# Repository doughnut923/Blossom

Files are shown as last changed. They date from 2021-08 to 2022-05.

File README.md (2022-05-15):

# Blossom

An open-sourced Alice/Arisu style keyboard case. Modified from [FateNozomi's Arisu](https://github.com/FateNozomi/arisu-case)

Hirakusu

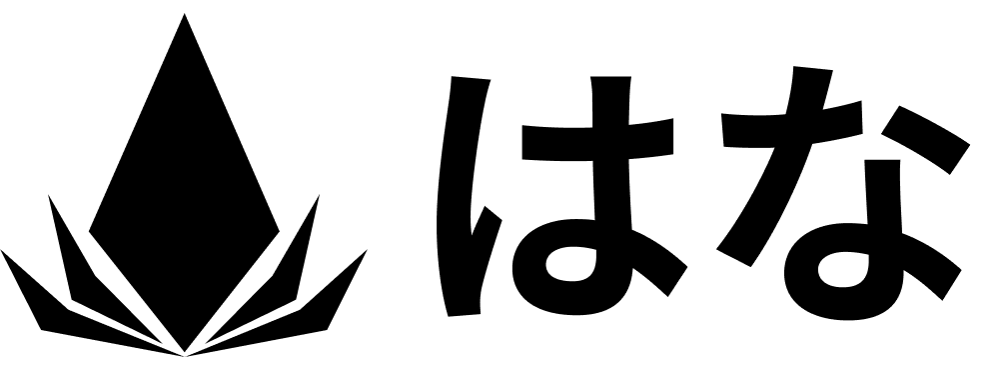
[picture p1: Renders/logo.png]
Hirakusu


## Features
- Designed for 3d printing
- Gasket Mounted Desgin using gasket strips on the side of the plate
   - Strip material: Poron Foam or Silicon Rubber
- Includes dxf files of sound dampening material between PCB and plate
- Compatible with [FateNozomi's PCB](https://github.com/FateNozomi/arisu-pcb)

## Layers

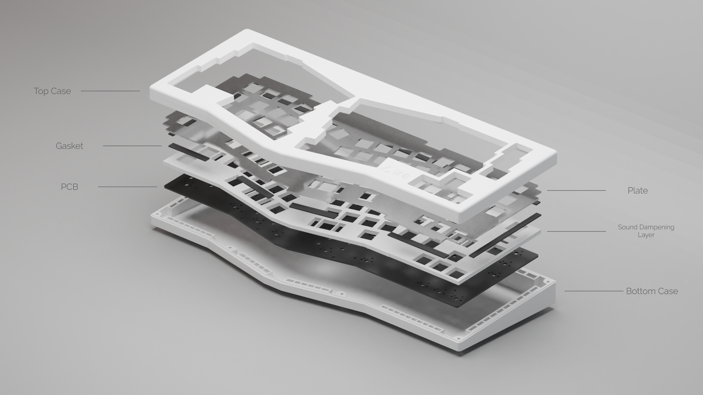
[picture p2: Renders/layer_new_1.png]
Layers


## Layout 

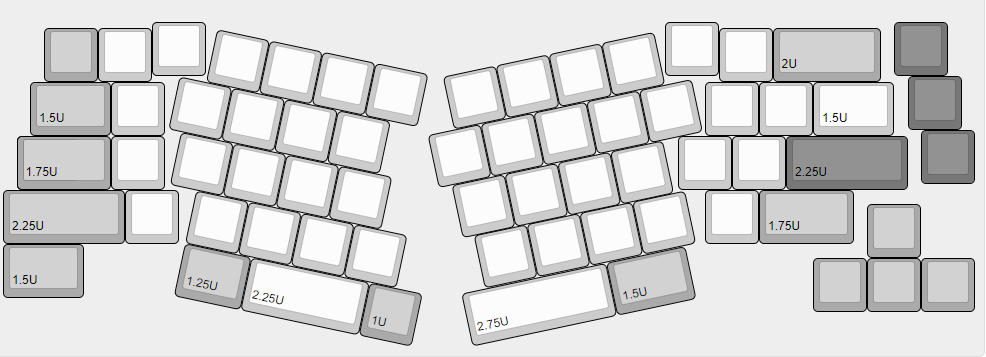
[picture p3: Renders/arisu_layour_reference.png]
layout ref


## Specifications 

- Dimensions: 30x142x375mm (DxHxW)
- Front Height: 16.5mm
- 5 degree typing angle

## About  the Repository
If you just want to build your own Blossom using the easiest steps just skip to [DIY Guide](#diy-guide)
Below is the contents of the respected folders in this GitHub Repo:
- `PCB files` - contains the Kicad project of the experimental version of the PCB(with underglow), modified from original FateNozomi's one.
- `Renders` - contains image assets.
- `blender` - contain Blender file of the case in case you need to do some edits to the model.
- ` case_stls` - stl files exported from Blender.
- `plate_dxfs` - contains dxf files for plate and gasket
- `production` - contains files necessary for DIY or production
- `qmk` - Modified keyboard firmware from arisu with added RGB underglow functionality.

# Notes
- **Use the files at your own risk**
- **PCB files are still under development,you can use it, but also at your own risk**

# DIY Guide
#### Things you need: 
| Item  | Image  | Description  | Related Files  | Place to Buy |
| --- | --- | --- | --- | --- |
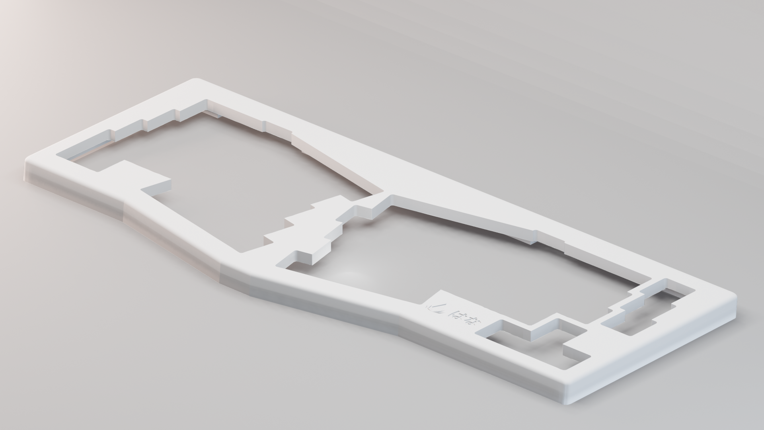
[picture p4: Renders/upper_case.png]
Upper Case
| Upper Case * 1  |   | Upper section of the case  | [U_Case.stl](https://github.com/DoughnutTheGuy/Blossom/blob/main/production/case/U_Case.stl)  |  [PCBWay](https://www.pcbway.com/rapid-prototyping/manufacture/?type=2&reffercode=TOP) |
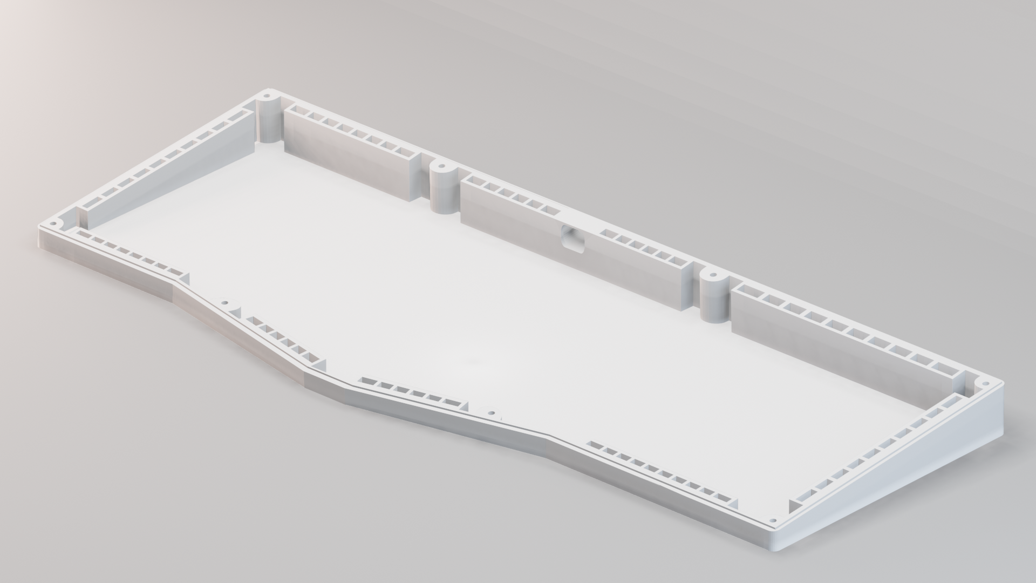
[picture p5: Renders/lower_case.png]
Lower Case
| Lower Case * 1  |   |  Lower Section of the case | [B_Case.stl](https://github.com/DoughnutTheGuy/Blossom/blob/main/production/case/B_Case.stl)  |  [PCBWay](https://www.pcbway.com/rapid-prototyping/manufacture/?type=2&reffercode=TOP) |
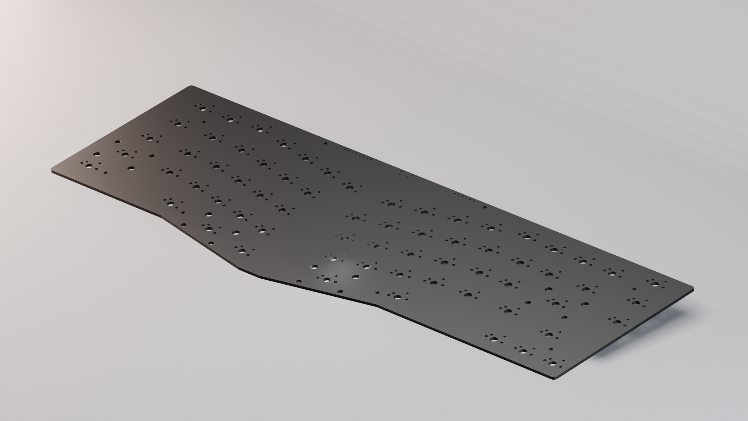
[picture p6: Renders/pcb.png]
PCB
|  PCB * 1  |   | Can be chosed from experimental version, which have backlight. Or original FateNozomi's version.  | Original: [gerber](https://github.com/DoughnutTheGuy/Blossom/blob/main/production/pcb/original/arisu-pcb-v1.1-gerber.zip) [bom](https://github.com/DoughnutTheGuy/Blossom/blob/main/production/pcb/original/arisu_bom.csv)  [CPL](https://github.com/DoughnutTheGuy/Blossom/blob/main/production/pcb/original/arisu-all-pos.csv)  Experimental: [gerber](https://github.com/DoughnutTheGuy/Blossom/blob/main/production/pcb/experimental/blossom-pcb.gerber.zip) [BOM](https://github.com/DoughnutTheGuy/Blossom/blob/main/production/pcb/experimental/arisu_bom.csv) [CPL](https://github.com/DoughnutTheGuy/Blossom/blob/main/production/pcb/experimental/arisu-all-pos.csv)| [JLPCB](https://jlcpcb.com) [PCBWay](https://www.pcbway.com) |
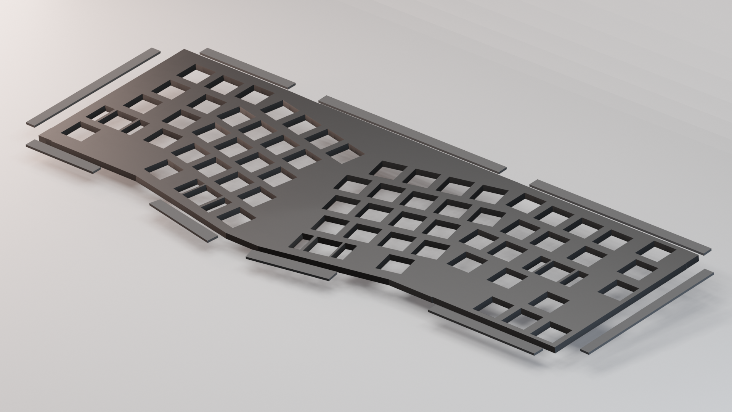
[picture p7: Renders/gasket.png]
Gasket
| Gasket & Sound Dampening Foam * 1  |   | Can be Poron or Silicon  | [gasket_n_sdl.dxf](https://github.com/DoughnutTheGuy/Blossom/blob/main/production/gasket/gasket_n_sdl.dxf)  | [TaoBao](https://item.taobao.com/item.htm?spm=a230r.1.14.38.46936e836dHYfA&id=637356500647&ns=1&abbucket=9#detail)  |
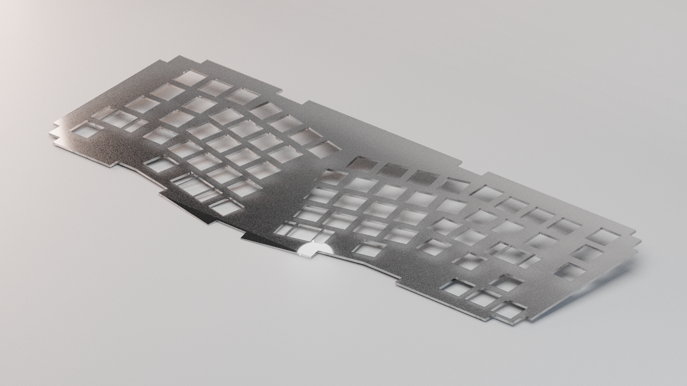
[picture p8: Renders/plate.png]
Plate
| Plate * 1 |   | /  |  [plate.dxf](https://github.com/DoughnutTheGuy/Blossom/blob/main/production/plate/plate.dxf) |  [Ponoko](https://www.ponoko.com/materials)  [TaoBao(PC)](https://item.taobao.com/item.htm?spm=a312a.7700824.w4004-18046735553.2.28ff1436zVjIGW&id=565729881968) [SendCutSend](https://sendcutsend.com/)|
| M2.5 Screws * 8 | /  | /  |  / | [Ebay](https://www.ebay.com/sch/i.html?_from=R40&_trksid=p2380057.m570.l1313&_nkw=m2.5+*+4+hex+screws&_sacat=0) [Taobao](https://detail.tmall.com/item.htm?id=18868040917&spm=a1z0k.7385993.0.0.58e537decwL3jP&skuId=4328080057495) |
| M2.5 Insert * 8 | /  | /  |  / |  [Amazon](https://www.amazon.com/Knurled-Threaded-Embedment-Assortment-M2-533-5%EF%BC%88100pcs%EF%BC%89/dp/B07SPWZT5G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) [Taobao](https://detail.tmall.com/item.htm?id=19528296472&spm=a1z0k.7385993.0.0.58e537decwL3jP) |

##### Other things you should probably have : Soldering Iron,  screw driver, switches, Hot Glue(Optional)

### Assembly
------------
**Step 1** - Install the switches into the plate

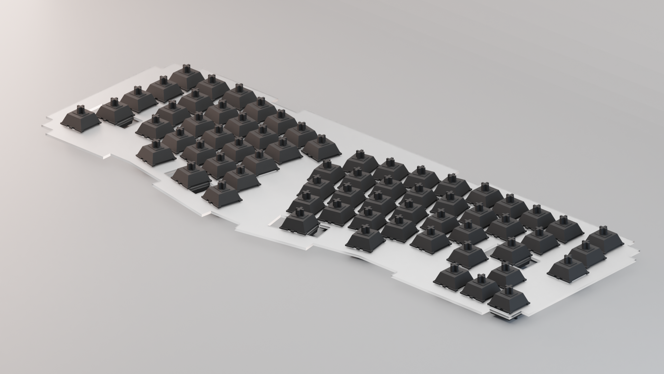
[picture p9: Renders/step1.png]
step 1


**Step 2** - place the sound dampening material between the plate and PCB

step 2

**Step 3** - Solder the switches

**Step 4** - Stick the gasket of the material of your choice to the extended positions on the plate

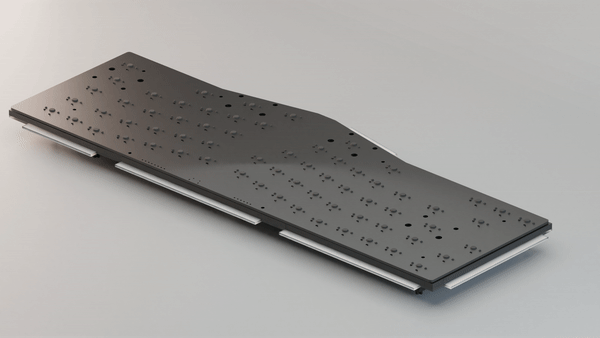
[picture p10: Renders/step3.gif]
step4


**Step 5**  - Install the M2.5 inserts in the 8 positions on the upper case shown below

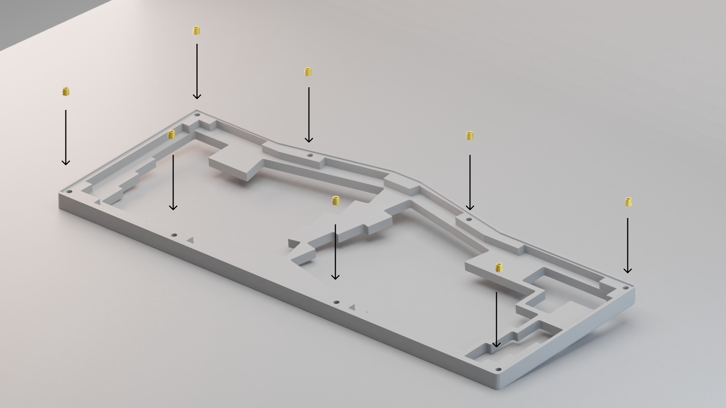
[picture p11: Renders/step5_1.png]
Step 5


**Step 6** - Place the plate with the pcb on top of the bottom case

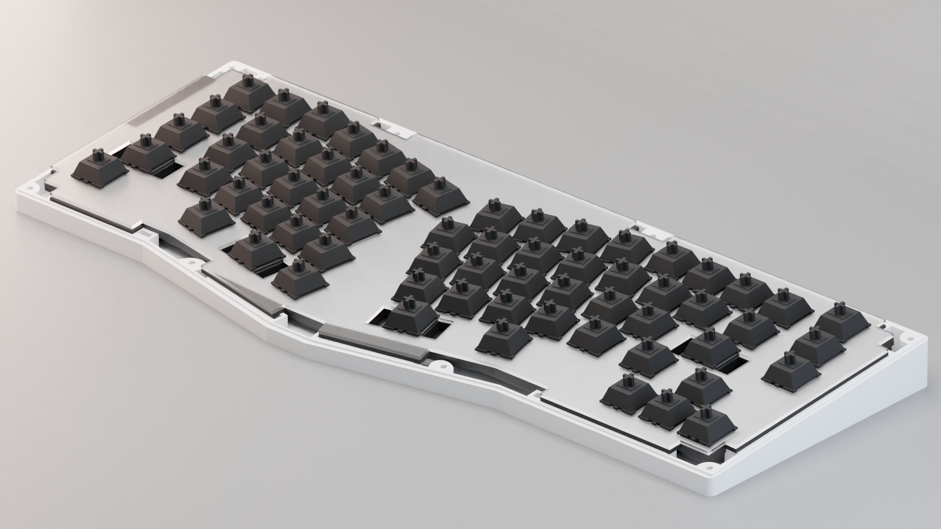
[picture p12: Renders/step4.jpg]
Step 6


**Step 7** - Cover it with the upper case

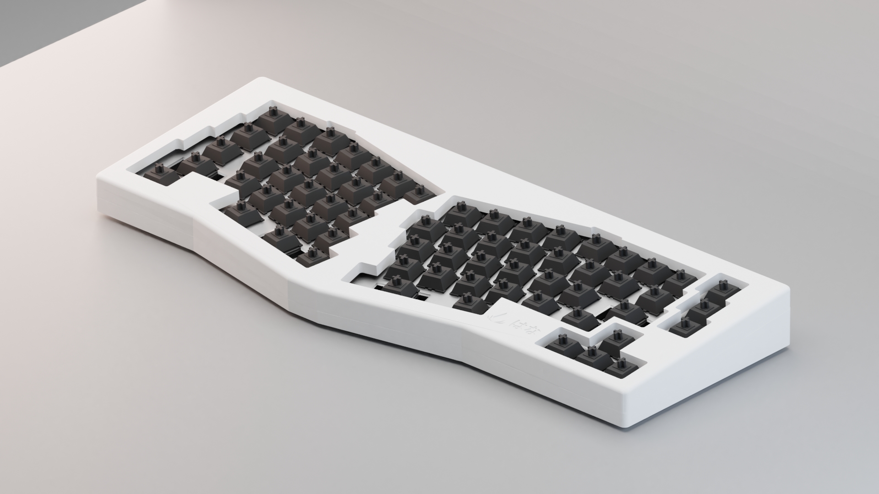
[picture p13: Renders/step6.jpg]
Step 7


**Step 8** - Install screw in the following positions to fix both upper and bottom case

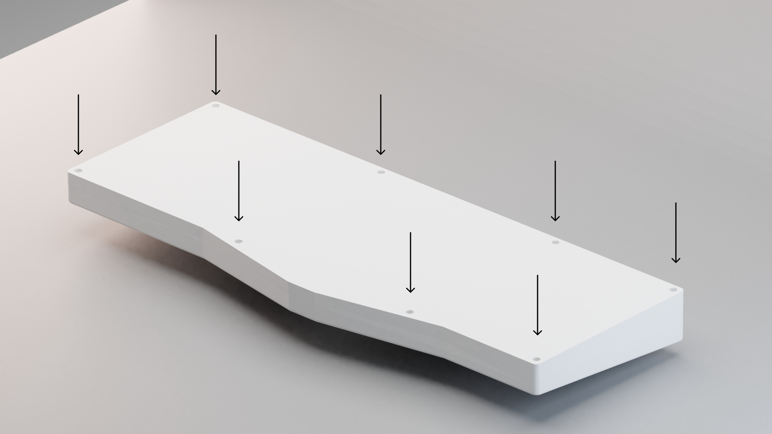
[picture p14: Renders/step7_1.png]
Final Step


**Final Step** - Connect your keyboard to a computer. Download the [Arisu Firmware from VIA](https://caniusevia.com/docs/download_firmware/#0) and fiash it to your keyboard. Tools such as [QMK Toolbox](https://github.com/qmk/qmk_toolbox) Is recommended. Here is a [quick guide](https://www.youtube.com/watch?v=fuBJbdCFF0Q&t=203s) on how to use QMK toolbox just for reference.

If you are using the experimental version. you need to change the `config.h` file's `RGB_DI_PIN`'s value to `F4`

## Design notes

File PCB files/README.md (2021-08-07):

This PCB is uder developnment

Only have support for underglow

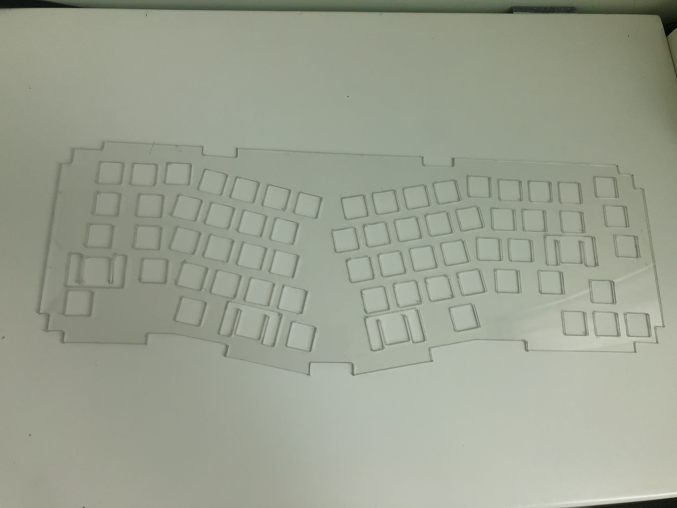
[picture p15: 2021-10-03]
Renders/proto_plate.jpg

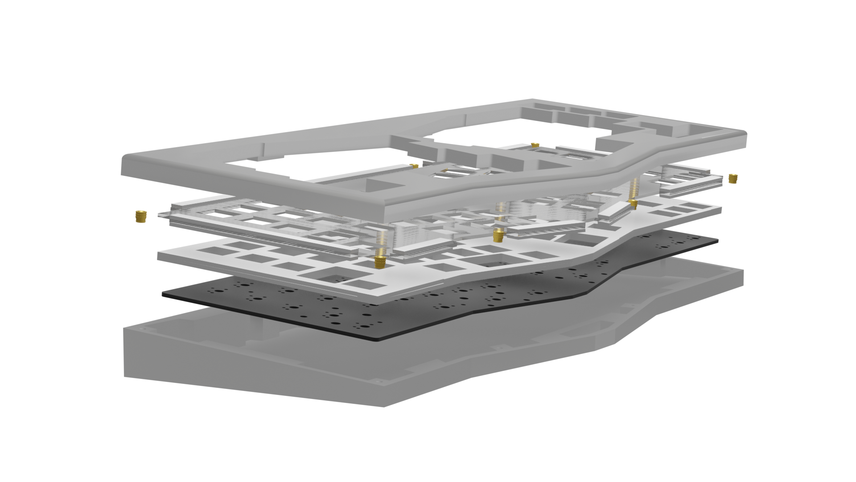
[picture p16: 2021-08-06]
Renders/layers.png

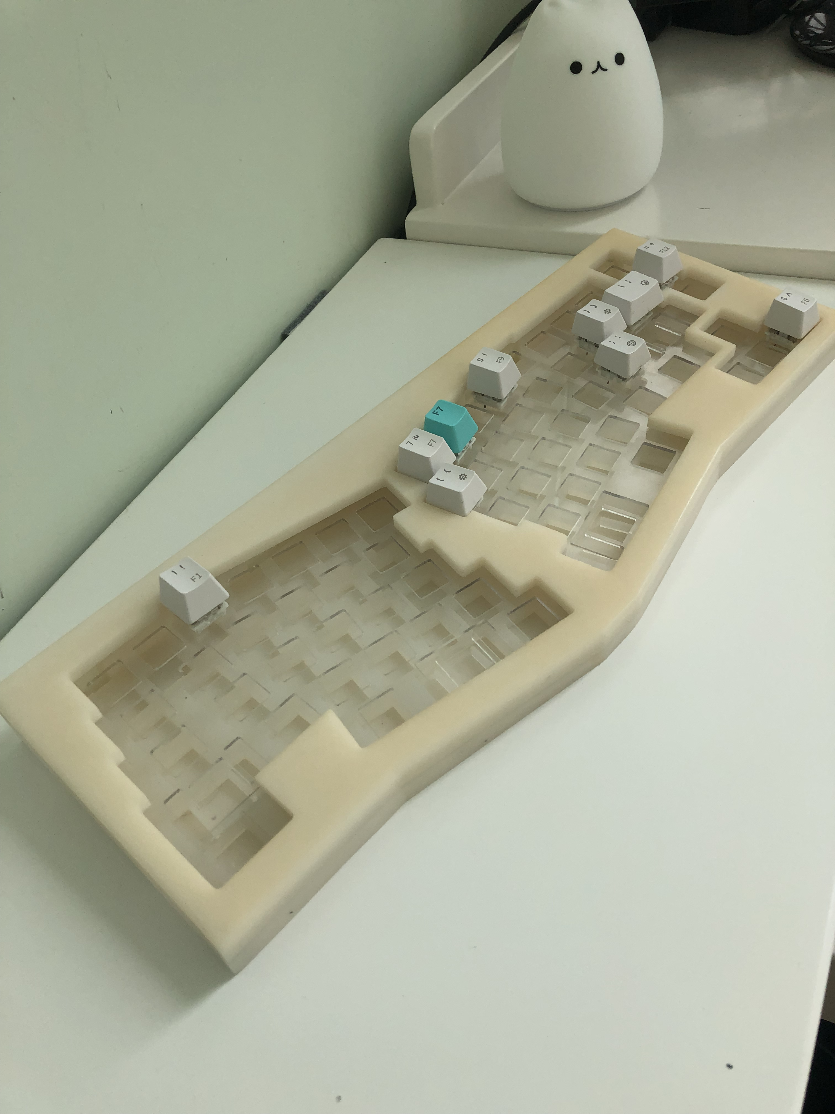
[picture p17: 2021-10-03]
Renders/proto_case.jpg

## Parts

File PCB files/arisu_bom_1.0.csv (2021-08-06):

Component | Description | Part | References | Value | Footprint | Quantity Per PCB | Datasheet
1 | Unpolarized capacitor | C | C6 C7 C8 C9 | 0.1uF | C_0805_HandSoldering | 4 | ~
2 | Unpolarized capacitor | C | C3 | 10uF | C_0805_HandSoldering | 1 | ~
3 | Unpolarized capacitor | C | C5 | 1uF | C_0805_HandSoldering | 1 | ~
4 | Unpolarized capacitor | C | C4 | 1uF (±10%) | C_0805_HandSoldering | 1 | ~
5 | Unpolarized capacitor | C | C1 C2 | 22pF | C_0805_HandSoldering | 2 | ~
6 | Diode | D | D1 D2 D3 D4 D5 D6 D7 D8 D9 D10 D11 D12 D13 D14 D15 D16 D17 D18 D19 D20 D21 D22 D23 D24 D25 D26 D27 D28 D29 D30 D31 D32 D33 D34 D35 D36 D37 D38 D39 D40 D41 D42 D43 D44 D45 D46 D47 D48 D49 D50 D51 D52 D53 D54 D55 D56 D57 D58 D59 D60 D61 D62 D63 D64 D65 D66 D67 | D | D_SOD-123 | 67 | ~
7 | Generic connector, single row, 01x01, script generated (kicad-library-utils/schlib/autogen/connector/) | Conn_01x01 | J13 | D+ | Pin_Header_Straight_1x01_Pitch2.54mm | 1 | ~
8 | Generic connector, single row, 01x01, script generated (kicad-library-utils/schlib/autogen/connector/) | Conn_01x01 | J14 | D- | Pin_Header_Straight_1x01_Pitch2.54mm | 1 | ~
9 | Generic connector, single row, 01x01, script generated (kicad-library-utils/schlib/autogen/connector/) | Conn_01x01 | J7 J15 | GND | Pin_Header_Straight_1x01_Pitch2.54mm | 2 | ~
10 | Generic connector, single row, 01x01, script generated (kicad-library-utils/schlib/autogen/connector/) | Conn_01x01 | J2 | MISO | Pin_Header_Straight_1x01_Pitch2.54mm | 1 | ~
11 | Generic connector, single row, 01x01, script generated (kicad-library-utils/schlib/autogen/connector/) | Conn_01x01 | J5 | MOSI | Pin_Header_Straight_1x01_Pitch2.54mm | 1 | ~
12 | Generic connector, single row, 01x01, script generated (kicad-library-utils/schlib/autogen/connector/) | Conn_01x01 | J8 | PF4 | Pin_Header_Straight_1x01_Pitch2.54mm | 1 | ~
13 | Generic connector, single row, 01x01, script generated (kicad-library-utils/schlib/autogen/connector/) | Conn_01x01 | J9 | PF5 | Pin_Header_Straight_1x01_Pitch2.54mm | 1 | ~
14 | Generic connector, single row, 01x01, script generated (kicad-library-utils/schlib/autogen/connector/) | Conn_01x01 | J10 | PF6 | Pin_Header_Straight_1x01_Pitch2.54mm | 1 | ~
15 | Generic connector, single row, 01x01, script generated (kicad-library-utils/schlib/autogen/connector/) | Conn_01x01 | J11 | PF7 | Pin_Header_Straight_1x01_Pitch2.54mm | 1 | ~
16 | Generic connector, single row, 01x01, script generated (kicad-library-utils/schlib/autogen/connector/) | Conn_01x01 | J6 | RES | Pin_Header_Straight_1x01_Pitch2.54mm | 1 | ~
17 | Generic connector, single row, 01x01, script generated (kicad-library-utils/schlib/autogen/connector/) | Conn_01x01 | J4 | SCK | Pin_Header_Straight_1x01_Pitch2.54mm | 1 | ~
18 | USB Micro Type B connector | USB_B_Micro | J1 | USB_B_Micro | USB_Micro-B_Molex-105017-0001 | 1 | ~
19 | Generic connector, single row, 01x01, script generated (kicad-library-utils/schlib/autogen/connector/) | Conn_01x01 | J3 J12 | VCC | Pin_Header_Straight_1x01_Pitch2.54mm | 2 | ~
20 | Resistor | R | R3 R4 | 10K | R_0805_HandSoldering | 2 | ~
21 | Resistor | R | R1 R2 | 22 | R_0805_HandSoldering | 2 | ~
22 | Push button switch, generic, two pins | SW_Push | SW1 SW6 SW7 SW8 SW9 SW10 SW11 SW12 SW13 SW15 SW16 SW17 SW18 SW19 SW20 SW21 SW22 SW24 SW25 SW26 SW27 SW28 SW29 SW30 SW31 SW32 SW33 SW34 SW35 SW36 SW38 SW39 SW40 SW41 SW42 SW43 SW44 SW45 SW47 SW48 SW49 SW50 SW51 SW52 SW53 SW55 SW56 SW58 SW59 SW61 SW62 SW63 SW64 SW65 SW66 SW67 | SW_Push | SW_Cherry_MX_1.00u_PCB | 56
23 | Push button switch, generic, two pins | SW_Push | SW2 SW5 SW14 SW46 SW60 | SW_Push | SW_Cherry_MX_1.50u_PCB | 5
24 | Push button switch, generic, two pins | SW_Push | SW23 | SW_Push | SW_Cherry_MX_2.00u_PCB_ReversedStabilizers | 1
25 | Push button switch, generic, two pins | SW_Push | SW3 SW54 | SW_Push | SW_Cherry_MX_1.75u_PCB | 2
26 | Push button switch, generic, two pins | SW_Push | SW37 | SW_Push | SW_Cherry_MX_2.75u_PCB_ReversedStabilizers | 1
27 | Push button switch, generic, two pins | SW_Push | SW4 | SW_Push | SW_Cherry_MX_2.25u_PCB | 1
28 | Push button switch, generic, two pins | SW_Push | SW57 | SW_Push | SW_Cherry_MX_2.25u_PCB_ReversedStabilizers | 1
29 | Push button switch, generic, two pins | SW_Push | SWR1 | SW_Push | SW_SPST_TL3342 | 1
30 | 16MHz, 32kB Flash, 2.5kB SRAM, 1kB EEPROM, USB 2.0, TQFP-44 | ATmega32U4-AU | U2 | ATmega32U4-AU | TQFP-44_10x10mm_Pitch0.8mm | 1 | http://ww1.microchip.com/downloads/en/DeviceDoc/Atmel-7766-8-bit-AVR-ATmega16U4-32U4_Datasheet.pdf
31 | Bidirectional ESD Protection Diode, SOT-23-6 | USBLC6-2SC6 | U1 | USBLC6-2SC6 | SOT-23-6_Handsoldering | 1 | http://www2.st.com/resource/en/datasheet/CD00050750.pdf
32 | Four pin crystal, GND on pins 2 and 4 | Crystal_GND24 | Y1 | Crystal_GND24 | Crystal_SMD_SeikoEpson_FA238-4pin_3.2x2.5mm_HandSoldering | 1 | ~
Component Groups: | 32
Component Count: | 166
Fitted Components: | 166
Number of PCBs: | 1
Total components: | 166
Schematic Version: | 1.0
Schematic Date:
BoM Date: | 2/10/2019 10:20:54 PM
Schematic Source: | D:\Users\Will\Documents\arisu-pcb\arisu.sch
KiCad Version: | Eeschema (5.0.2)-1

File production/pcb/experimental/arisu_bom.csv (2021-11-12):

Desginator | Comment | Footprint
C1, C2 | 22pF | Capacitor_SMD:C_0805_2012Metric
C3 | 10uF | Capacitor_SMD:C_0805_2012Metric
C4 | 1uF (+-10%) | Capacitor_SMD:C_0805_2012Metric
C5 | 1uF | Capacitor_SMD:C_0805_2012Metric
C6, C7, C8, C9 | 0.1uF | Capacitor_SMD:C_0805_2012Metric
D1, D2, D3, D4, D5, D6, D7, D8, D9, D10, D11, D12, D13, D14, D15, D16, D17, D18, D19, D20, D21, D22, D23, D24, D25, D26, D27, D28, D29, D30, D31, D32, D33, D34, D35, D36, D37, D38, D39, D40, D41, D42, D43, D44, D45, D46, D47, D48, D49, D50, D51, D52, D53, D54, D55, D56, D57, D58, D59, D60, D61, D62, D63, D64, D65, D66, D67 | D | Diodes_SMD:D_SOD-123
D68, D69, D70, D71, D72, D73, D74, D75, D76, D77, D78, D79, D80, D81, D82, D83 | WS2812B | LED_SMD:LED_WS2812B_PLCC4_5.0x5.0mm_P3.2mm
H1, H2, H3, H4, H5, H6, H7, H8 | MountingHole | Mounting_Holes:MountingHole_2.2mm_M2_Pad
J1 | USB_B_Micro | Connectors_USB:USB_Micro-B_Molex-105017-0001
R1, R2 | 22 | Resistor_SMD:R_0805_2012Metric
R3, R4 | 10K | Resistor_SMD:R_0805_2012Metric
R5 | 500 | Resistor_SMD:R_0805_2012Metric
SWR1 | SW_Push | Buttons_Switches_SMD:SW_SPST_TL3342
U1 | USBLC6-2SC6 | TO_SOT_Packages_SMD:SOT-23-6_Handsoldering
U2 | ATmega32U4-AU | Housings_QFP:TQFP-44_10x10mm_Pitch0.8mm
Y1 | Crystal_GND24 | Crystal:Crystal_SMD_3225-4Pin_3.2x2.5mm

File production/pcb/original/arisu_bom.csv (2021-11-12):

Designator | Comment | Footprint
C1, C2 | 22pF | Capacitors_SMD:C_0805_HandSoldering
C3 | 10uF | Capacitors_SMD:C_0805_HandSoldering
C4 | 1uF (±10%) | Capacitors_SMD:C_0805_HandSoldering
C5 | 1uF | Capacitors_SMD:C_0805_HandSoldering
C6, C7, C8, C9 | 0.1uF | Capacitors_SMD:C_0805_HandSoldering
D1, D2, D3, D4, D5, D6, D7, D8, D9, D10, D11, D12, D13, D14, D15, D16, D17, D18, D19, D20, D21, D22, D23, D24, D25, D26, D27, D28, D29, D30, D31, D32, D33, D34, D35, D36, D37, D38, D39, D40, D41, D42, D43, D44, D45, D46, D47, D48, D49, D50, D51, D52, D53, D54, D55, D56, D57, D58, D59, D60, D61, D62, D63, D64, D65, D66, D67 | D | Diodes_SMD:D_SOD-123
H1, H2, H3, H4, H5, H6, H7, H8 | MountingHole | Mounting_Holes:MountingHole_2.2mm_M2_Pad
J1 | USB_B_Micro | Connectors_USB:USB_Micro-B_Molex-105017-0001
J2 | MISO | Pin_Headers:Pin_Header_Straight_1x01_Pitch2.54mm
J3, J12 | VCC | Pin_Headers:Pin_Header_Straight_1x01_Pitch2.54mm
J4 | SCK | Pin_Headers:Pin_Header_Straight_1x01_Pitch2.54mm
J5 | MOSI | Pin_Headers:Pin_Header_Straight_1x01_Pitch2.54mm
J6 | RES | Pin_Headers:Pin_Header_Straight_1x01_Pitch2.54mm
J7, J15 | GND | Pin_Headers:Pin_Header_Straight_1x01_Pitch2.54mm
J8 | PF4 | Pin_Headers:Pin_Header_Straight_1x01_Pitch2.54mm
J9 | PF5 | Pin_Headers:Pin_Header_Straight_1x01_Pitch2.54mm
J10 | PF6 | Pin_Headers:Pin_Header_Straight_1x01_Pitch2.54mm
J11 | PF7 | Pin_Headers:Pin_Header_Straight_1x01_Pitch2.54mm
J13 | D+ | Pin_Headers:Pin_Header_Straight_1x01_Pitch2.54mm
J14 | D- | Pin_Headers:Pin_Header_Straight_1x01_Pitch2.54mm
R1, R2 | 22 | Resistors_SMD:R_0805_HandSoldering
R3, R4 | 10K | Resistors_SMD:R_0805_HandSoldering
SW1, SW6, SW7, SW8, SW9, SW10, SW11, SW12, SW13, SW15, SW16, SW17, SW18, SW19, SW20, SW21, SW22, SW24, SW25, SW26, SW27, SW28, SW29, SW30, SW31, SW32, SW33, SW34, SW35, SW36, SW38, SW39, SW40, SW41, SW42, SW43, SW44, SW45, SW47, SW48, SW49, SW50, SW51, SW52, SW53, SW55, SW56, SW58, SW59, SW61, SW62, SW63, SW64, SW65, SW66, SW67 | SW_Push | MX_Switch:SW_Cherry_MX_1.00u_PCB
SW2, SW5, SW14, SW46, SW60 | SW_Push | MX_Switch:SW_Cherry_MX_1.50u_PCB
SW3, SW54 | SW_Push | MX_Switch:SW_Cherry_MX_1.75u_PCB
SW4 | SW_Push | MX_Switch:SW_Cherry_MX_2.25u_PCB
SW23 | SW_Push | MX_Switch:SW_Cherry_MX_2.00u_PCB_ReversedStabilizers
SW37 | SW_Push | MX_Switch:SW_Cherry_MX_2.75u_PCB_ReversedStabilizers
SW57 | SW_Push | MX_Switch:SW_Cherry_MX_2.25u_PCB_ReversedStabilizers
SWR1 | SW_Push | Buttons_Switches_SMD:SW_SPST_TL3342
U1 | USBLC6-2SC6 | TO_SOT_Packages_SMD:SOT-23-6_Handsoldering
U2 | ATmega32U4-AU | Housings_QFP:TQFP-44_10x10mm_Pitch0.8mm
Y1 | Crystal_GND24 | Crystals:Crystal_SMD_SeikoEpson_FA238-4pin_3.2x2.5mm_HandSoldering

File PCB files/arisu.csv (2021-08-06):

Source: | C:\Users\asus\Desktop\Keybord Project\Final Folder\arisu-pcb-master\arisu.sch
Date: | 10/07/2021 18:01:36
Tool: | Eeschema (5.1.9)-1
Generator: | D:\Program Files\KiCad\bin\scripting\plugins/bom_csv_grouped_by_value.py
Component Count: | 191
Individual Components:
Item | Qty | Reference(s) | Value | LibPart | Footprint | Datasheet
 |  | C1 | 22pF | Device:C | Capacitor_SMD:C_0805_2012Metric | ~
 |  | C2 | 22pF | Device:C | Capacitor_SMD:C_0805_2012Metric | ~
 |  | C3 | 10uF | Device:C | Capacitor_SMD:C_0805_2012Metric | ~
 |  | C4 | 1uF (±10%) | Device:C | Capacitor_SMD:C_0805_2012Metric | ~
 |  | C5 | 1uF | Device:C | Capacitor_SMD:C_0805_2012Metric | ~
 |  | C6 | 0.1uF | Device:C | Capacitor_SMD:C_0805_2012Metric | ~
 |  | C7 | 0.1uF | Device:C | Capacitor_SMD:C_0805_2012Metric | ~
 |  | C8 | 0.1uF | Device:C | Capacitor_SMD:C_0805_2012Metric | ~
 |  | C9 | 0.1uF | Device:C | Capacitor_SMD:C_0805_2012Metric | ~
 |  | D1 | D | Device:D | Diodes_SMD:D_SOD-123 | ~
 |  | D2 | D | Device:D | Diodes_SMD:D_SOD-123 | ~
 |  | D3 | D | Device:D | Diodes_SMD:D_SOD-123 | ~
 |  | D4 | D | Device:D | Diodes_SMD:D_SOD-123 | ~
 |  | D5 | D | Device:D | Diodes_SMD:D_SOD-123 | ~
 |  | D6 | D | Device:D | Diodes_SMD:D_SOD-123 | ~
 |  | D7 | D | Device:D | Diodes_SMD:D_SOD-123 | ~
 |  | D8 | D | Device:D | Diodes_SMD:D_SOD-123 | ~
 |  | D9 | D | Device:D | Diodes_SMD:D_SOD-123 | ~
 |  | D10 | D | Device:D | Diodes_SMD:D_SOD-123 | ~
 |  | D11 | D | Device:D | Diodes_SMD:D_SOD-123 | ~
 |  | D12 | D | Device:D | Diodes_SMD:D_SOD-123 | ~
 |  | D13 | D | Device:D | Diodes_SMD:D_SOD-123 | ~
 |  | D14 | D | Device:D | Diodes_SMD:D_SOD-123 | ~
 |  | D15 | D | Device:D | Diodes_SMD:D_SOD-123 | ~
 |  | D16 | D | Device:D | Diodes_SMD:D_SOD-123 | ~
 |  | D17 | D | Device:D | Diodes_SMD:D_SOD-123 | ~
 |  | D18 | D | Device:D | Diodes_SMD:D_SOD-123 | ~
 |  | D19 | D | Device:D | Diodes_SMD:D_SOD-123 | ~
 |  | D20 | D | Device:D | Diodes_SMD:D_SOD-123 | ~
 |  | D21 | D | Device:D | Diodes_SMD:D_SOD-123 | ~
 |  | D22 | D | Device:D | Diodes_SMD:D_SOD-123 | ~
 |  | D23 | D | Device:D | Diodes_SMD:D_SOD-123 | ~
 |  | D24 | D | Device:D | Diodes_SMD:D_SOD-123 | ~
 |  | D25 | D | Device:D | Diodes_SMD:D_SOD-123 | ~
 |  | D26 | D | Device:D | Diodes_SMD:D_SOD-123 | ~
 |  | D27 | D | Device:D | Diodes_SMD:D_SOD-123 | ~
 |  | D28 | D | Device:D | Diodes_SMD:D_SOD-123 | ~
 |  | D29 | D | Device:D | Diodes_SMD:D_SOD-123 | ~
 |  | D30 | D | Device:D | Diodes_SMD:D_SOD-123 | ~
 |  | D31 | D | Device:D | Diodes_SMD:D_SOD-123 | ~
 |  | D32 | D | Device:D | Diodes_SMD:D_SOD-123 | ~
 |  | D33 | D | Device:D | Diodes_SMD:D_SOD-123 | ~
 |  | D34 | D | Device:D | Diodes_SMD:D_SOD-123 | ~
 |  | D35 | D | Device:D | Diodes_SMD:D_SOD-123 | ~
 |  | D36 | D | Device:D | Diodes_SMD:D_SOD-123 | ~
 |  | D37 | D | Device:D | Diodes_SMD:D_SOD-123 | ~
 |  | D38 | D | Device:D | Diodes_SMD:D_SOD-123 | ~
 |  | D39 | D | Device:D | Diodes_SMD:D_SOD-123 | ~
 |  | D40 | D | Device:D | Diodes_SMD:D_SOD-123 | ~
 |  | D41 | D | Device:D | Diodes_SMD:D_SOD-123 | ~
 |  | D42 | D | Device:D | Diodes_SMD:D_SOD-123 | ~
 |  | D43 | D | Device:D | Diodes_SMD:D_SOD-123 | ~
 |  | D44 | D | Device:D | Diodes_SMD:D_SOD-123 | ~
 |  | D45 | D | Device:D | Diodes_SMD:D_SOD-123 | ~
 |  | D46 | D | Device:D | Diodes_SMD:D_SOD-123 | ~
 |  | D47 | D | Device:D | Diodes_SMD:D_SOD-123 | ~
 |  | D48 | D | Device:D | Diodes_SMD:D_SOD-123 | ~
 |  | D49 | D | Device:D | Diodes_SMD:D_SOD-123 | ~
 |  | D50 | D | Device:D | Diodes_SMD:D_SOD-123 | ~
 |  | D51 | D | Device:D | Diodes_SMD:D_SOD-123 | ~
 |  | D52 | D | Device:D | Diodes_SMD:D_SOD-123 | ~
 |  | D53 | D | Device:D | Diodes_SMD:D_SOD-123 | ~
 |  | D54 | D | Device:D | Diodes_SMD:D_SOD-123 | ~
 |  | D55 | D | Device:D | Diodes_SMD:D_SOD-123 | ~
 |  | D56 | D | Device:D | Diodes_SMD:D_SOD-123 | ~
 |  | D57 | D | Device:D | Diodes_SMD:D_SOD-123 | ~
 |  | D58 | D | Device:D | Diodes_SMD:D_SOD-123 | ~
 |  | D59 | D | Device:D | Diodes_SMD:D_SOD-123 | ~
 |  | D60 | D | Device:D | Diodes_SMD:D_SOD-123 | ~
 |  | D61 | D | Device:D | Diodes_SMD:D_SOD-123 | ~
 |  | D62 | D | Device:D | Diodes_SMD:D_SOD-123 | ~
 |  | D63 | D | Device:D | Diodes_SMD:D_SOD-123 | ~
 |  | D64 | D | Device:D | Diodes_SMD:D_SOD-123 | ~
 |  | D65 | D | Device:D | Diodes_SMD:D_SOD-123 | ~
 |  | D66 | D | Device:D | Diodes_SMD:D_SOD-123 | ~
 |  | D67 | D | Device:D | Diodes_SMD:D_SOD-123 | ~
 |  | D68 | WS2812B | LED:WS2812B | LED_SMD:LED_WS2812B_PLCC4_5.0x5.0mm_P3.2mm | https://cdn-shop.adafruit.com/datasheets/WS2812B.pdf
 |  | D69 | WS2812B | LED:WS2812B | LED_SMD:LED_WS2812B_PLCC4_5.0x5.0mm_P3.2mm | https://cdn-shop.adafruit.com/datasheets/WS2812B.pdf
 |  | D70 | WS2812B | LED:WS2812B | LED_SMD:LED_WS2812B_PLCC4_5.0x5.0mm_P3.2mm | https://cdn-shop.adafruit.com/datasheets/WS2812B.pdf
 |  | D71 | WS2812B | LED:WS2812B | LED_SMD:LED_WS2812B_PLCC4_5.0x5.0mm_P3.2mm | https://cdn-shop.adafruit.com/datasheets/WS2812B.pdf
 |  | D72 | WS2812B | LED:WS2812B | LED_SMD:LED_WS2812B_PLCC4_5.0x5.0mm_P3.2mm | https://cdn-shop.adafruit.com/datasheets/WS2812B.pdf
 |  | D73 | WS2812B | LED:WS2812B | LED_SMD:LED_WS2812B_PLCC4_5.0x5.0mm_P3.2mm | https://cdn-shop.adafruit.com/datasheets/WS2812B.pdf
 |  | D74 | WS2812B | LED:WS2812B | LED_SMD:LED_WS2812B_PLCC4_5.0x5.0mm_P3.2mm | https://cdn-shop.adafruit.com/datasheets/WS2812B.pdf
 |  | D75 | WS2812B | LED:WS2812B | LED_SMD:LED_WS2812B_PLCC4_5.0x5.0mm_P3.2mm | https://cdn-shop.adafruit.com/datasheets/WS2812B.pdf
 |  | D76 | WS2812B | LED:WS2812B | LED_SMD:LED_WS2812B_PLCC4_5.0x5.0mm_P3.2mm | https://cdn-shop.adafruit.com/datasheets/WS2812B.pdf
 |  | D77 | WS2812B | LED:WS2812B | LED_SMD:LED_WS2812B_PLCC4_5.0x5.0mm_P3.2mm | https://cdn-shop.adafruit.com/datasheets/WS2812B.pdf
 |  | D78 | WS2812B | LED:WS2812B | LED_SMD:LED_WS2812B_PLCC4_5.0x5.0mm_P3.2mm | https://cdn-shop.adafruit.com/datasheets/WS2812B.pdf
 |  | D79 | WS2812B | LED:WS2812B | LED_SMD:LED_WS2812B_PLCC4_5.0x5.0mm_P3.2mm | https://cdn-shop.adafruit.com/datasheets/WS2812B.pdf
 |  | D80 | WS2812B | LED:WS2812B | LED_SMD:LED_WS2812B_PLCC4_5.0x5.0mm_P3.2mm | https://cdn-shop.adafruit.com/datasheets/WS2812B.pdf
 |  | D81 | WS2812B | LED:WS2812B | LED_SMD:LED_WS2812B_PLCC4_5.0x5.0mm_P3.2mm | https://cdn-shop.adafruit.com/datasheets/WS2812B.pdf
 |  | D82 | WS2812B | LED:WS2812B | LED_SMD:LED_WS2812B_PLCC4_5.0x5.0mm_P3.2mm | https://cdn-shop.adafruit.com/datasheets/WS2812B.pdf
 |  | D83 | WS2812B | LED:WS2812B | LED_SMD:LED_WS2812B_PLCC4_5.0x5.0mm_P3.2mm | https://cdn-shop.adafruit.com/datasheets/WS2812B.pdf
 |  | H1 | MountingHole | Mechanical:MountingHole | Mounting_Holes:MountingHole_2.2mm_M2_Pad | ~
 |  | H2 | MountingHole | Mechanical:MountingHole | Mounting_Holes:MountingHole_2.2mm_M2_Pad | ~
 |  | H3 | MountingHole | Mechanical:MountingHole | Mounting_Holes:MountingHole_2.2mm_M2_Pad | ~
 |  | H4 | MountingHole | Mechanical:MountingHole | Mounting_Holes:MountingHole_2.2mm_M2_Pad | ~
 |  | H5 | MountingHole | Mechanical:MountingHole | Mounting_Holes:MountingHole_2.2mm_M2_Pad | ~
 |  | H6 | MountingHole | Mechanical:MountingHole | Mounting_Holes:MountingHole_2.2mm_M2_Pad | ~
 |  | H7 | MountingHole | Mechanical:MountingHole | Mounting_Holes:MountingHole_2.2mm_M2_Pad | ~
 |  | H8 | MountingHole | Mechanical:MountingHole | Mounting_Holes:MountingHole_2.2mm_M2_Pad | ~
 |  | J1 | USB_B_Micro | Connector:USB_B_Micro | Connectors_USB:USB_Micro-B_Molex-105017-0001 | ~
 |  | J2 | MISO | Connector_Generic:Conn_01x01 | Pin_Headers:Pin_Header_Straight_1x01_Pitch2.54mm | ~
 |  | J3 | VCC | Connector_Generic:Conn_01x01 | Pin_Headers:Pin_Header_Straight_1x01_Pitch2.54mm | ~
 |  | J4 | SCK | Connector_Generic:Conn_01x01 | Pin_Headers:Pin_Header_Straight_1x01_Pitch2.54mm | ~
 |  | J5 | MOSI | Connector_Generic:Conn_01x01 | Pin_Headers:Pin_Header_Straight_1x01_Pitch2.54mm | ~
 |  | J6 | RES | Connector_Generic:Conn_01x01 | Pin_Headers:Pin_Header_Straight_1x01_Pitch2.54mm | ~
 |  | J7 | GND | Connector_Generic:Conn_01x01 | Pin_Headers:Pin_Header_Straight_1x01_Pitch2.54mm | ~
 |  | J8 | PF4 | Connector_Generic:Conn_01x01 | Pin_Headers:Pin_Header_Straight_1x01_Pitch2.54mm | ~
 |  | J9 | PF5 | Connector_Generic:Conn_01x01 | Pin_Headers:Pin_Header_Straight_1x01_Pitch2.54mm | ~
 |  | J10 | PF6 | Connector_Generic:Conn_01x01 | Pin_Headers:Pin_Header_Straight_1x01_Pitch2.54mm | ~
 |  | J11 | PF7 | Connector_Generic:Conn_01x01 | Pin_Headers:Pin_Header_Straight_1x01_Pitch2.54mm | ~
 |  | J12 | VCC | Connector_Generic:Conn_01x01 | Pin_Headers:Pin_Header_Straight_1x01_Pitch2.54mm | ~
 |  | J13 | D+ | Connector_Generic:Conn_01x01 | Pin_Headers:Pin_Header_Straight_1x01_Pitch2.54mm | ~
 |  | J14 | D- | Connector_Generic:Conn_01x01 | Pin_Headers:Pin_Header_Straight_1x01_Pitch2.54mm | ~
 |  | J15 | GND | Connector_Generic:Conn_01x01 | Pin_Headers:Pin_Header_Straight_1x01_Pitch2.54mm | ~
 |  | R1 | 22 | Device:R | Resistor_SMD:R_0805_2012Metric | ~
 |  | R2 | 22 | Device:R | Resistor_SMD:R_0805_2012Metric | ~
 |  | R3 | 10K | Device:R | Resistor_SMD:R_0805_2012Metric | ~
 |  | R4 | 10K | Device:R | Resistor_SMD:R_0805_2012Metric | ~
 |  | R5 | 500 | Device:R | Resistor_SMD:R_0805_2012Metric | ~
 |  | SW1 | SW_Push | Switch:SW_Push | MX_Switch:SW_Cherry_MX_1.00u_PCB
 |  | SW2 | SW_Push | Switch:SW_Push | MX_Switch:SW_Cherry_MX_1.50u_PCB
 |  | SW3 | SW_Push | Switch:SW_Push | MX_Switch:SW_Cherry_MX_1.75u_PCB
 |  | SW4 | SW_Push | Switch:SW_Push | MX_Switch:SW_Cherry_MX_2.25u_PCB
 |  | SW5 | SW_Push | Switch:SW_Push | MX_Switch:SW_Cherry_MX_1.50u_PCB
 |  | SW6 | SW_Push | Switch:SW_Push | MX_Switch:SW_Cherry_MX_1.00u_PCB
 |  | SW7 | SW_Push | Switch:SW_Push | MX_Switch:SW_Cherry_MX_1.00u_PCB
 |  | SW8 | SW_Push | Switch:SW_Push | MX_Switch:SW_Cherry_MX_1.00u_PCB
 |  | SW9 | SW_Push | Switch:SW_Push | MX_Switch:SW_Cherry_MX_1.00u_PCB
 |  | SW10 | SW_Push | Switch:SW_Push | MX_Switch:SW_Cherry_MX_1.00u_PCB
 |  | SW11 | SW_Push | Switch:SW_Push | MX_Switch:SW_Cherry_MX_1.00u_PCB
 |  | SW12 | SW_Push | Switch:SW_Push | MX_Switch:SW_Cherry_MX_1.00u_PCB
 |  | SW13 | SW_Push | Switch:SW_Push | MX_Switch:SW_Cherry_MX_1.00u_PCB
 |  | SW14 | SW_Push | Switch:SW_Push | MX_Switch:SW_Cherry_MX_1.50u_PCB
 |  | SW15 | SW_Push | Switch:SW_Push | MX_Switch:SW_Cherry_MX_1.00u_PCB
 |  | SW16 | SW_Push | Switch:SW_Push | MX_Switch:SW_Cherry_MX_1.00u_PCB
 |  | SW17 | SW_Push | Switch:SW_Push | MX_Switch:SW_Cherry_MX_1.00u_PCB
 |  | SW18 | SW_Push | Switch:SW_Push | MX_Switch:SW_Cherry_MX_1.00u_PCB
 |  | SW19 | SW_Push | Switch:SW_Push | MX_Switch:SW_Cherry_MX_1.00u_PCB
 |  | SW20 | SW_Push | Switch:SW_Push | MX_Switch:SW_Cherry_MX_1.00u_PCB
 |  | SW21 | SW_Push | Switch:SW_Push | MX_Switch:SW_Cherry_MX_1.00u_PCB
 |  | SW22 | SW_Push | Switch:SW_Push | MX_Switch:SW_Cherry_MX_1.00u_PCB
 |  | SW23 | SW_Push | Switch:SW_Push | MX_Switch:SW_Cherry_MX_2.00u_PCB_ReversedStabilizers
 |  | SW24 | SW_Push | Switch:SW_Push | MX_Switch:SW_Cherry_MX_1.00u_PCB
 |  | SW25 | SW_Push | Switch:SW_Push | MX_Switch:SW_Cherry_MX_1.00u_PCB
 |  | SW26 | SW_Push | Switch:SW_Push | MX_Switch:SW_Cherry_MX_1.00u_PCB
 |  | SW27 | SW_Push | Switch:SW_Push | MX_Switch:SW_Cherry_MX_1.00u_PCB
 |  | SW28 | SW_Push | Switch:SW_Push | MX_Switch:SW_Cherry_MX_1.00u_PCB
 |  | SW29 | SW_Push | Switch:SW_Push | MX_Switch:SW_Cherry_MX_1.00u_PCB
 |  | SW30 | SW_Push | Switch:SW_Push | MX_Switch:SW_Cherry_MX_1.00u_PCB
 |  | SW31 | SW_Push | Switch:SW_Push | MX_Switch:SW_Cherry_MX_1.00u_PCB
 |  | SW32 | SW_Push | Switch:SW_Push | MX_Switch:SW_Cherry_MX_1.00u_PCB
 |  | SW33 | SW_Push | Switch:SW_Push | MX_Switch:SW_Cherry_MX_1.00u_PCB
 |  | SW34 | SW_Push | Switch:SW_Push | MX_Switch:SW_Cherry_MX_1.00u_PCB
 |  | SW35 | SW_Push | Switch:SW_Push | MX_Switch:SW_Cherry_MX_1.00u_PCB
 |  | SW36 | SW_Push | Switch:SW_Push | MX_Switch:SW_Cherry_MX_1.00u_PCB
 |  | SW37 | SW_Push | Switch:SW_Push | MX_Switch:SW_Cherry_MX_2.75u_PCB_ReversedStabilizers
 |  | SW38 | SW_Push | Switch:SW_Push | MX_Switch:SW_Cherry_MX_1.00u_PCB
 |  | SW39 | SW_Push | Switch:SW_Push | MX_Switch:SW_Cherry_MX_1.00u_PCB
 |  | SW40 | SW_Push | Switch:SW_Push | MX_Switch:SW_Cherry_MX_1.00u_PCB
 |  | SW41 | SW_Push | Switch:SW_Push | MX_Switch:SW_Cherry_MX_1.00u_PCB
 |  | SW42 | SW_Push | Switch:SW_Push | MX_Switch:SW_Cherry_MX_1.00u_PCB
 |  | SW43 | SW_Push | Switch:SW_Push | MX_Switch:SW_Cherry_MX_1.00u_PCB
 |  | SW44 | SW_Push | Switch:SW_Push | MX_Switch:SW_Cherry_MX_1.00u_PCB
 |  | SW45 | SW_Push | Switch:SW_Push | MX_Switch:SW_Cherry_MX_1.00u_PCB
 |  | SW46 | SW_Push | Switch:SW_Push | MX_Switch:SW_Cherry_MX_1.50u_PCB
 |  | SW47 | SW_Push | Switch:SW_Push | MX_Switch:SW_Cherry_MX_1.00u_PCB
 |  | SW48 | SW_Push | Switch:SW_Push | MX_Switch:SW_Cherry_MX_1.00u_PCB
 |  | SW49 | SW_Push | Switch:SW_Push | MX_Switch:SW_Cherry_MX_1.00u_PCB
 |  | SW50 | SW_Push | Switch:SW_Push | MX_Switch:SW_Cherry_MX_1.00u_PCB
 |  | SW51 | SW_Push | Switch:SW_Push | MX_Switch:SW_Cherry_MX_1.00u_PCB
 |  | SW52 | SW_Push | Switch:SW_Push | MX_Switch:SW_Cherry_MX_1.00u_PCB
 |  | SW53 | SW_Push | Switch:SW_Push | MX_Switch:SW_Cherry_MX_1.00u_PCB
 |  | SW54 | SW_Push | Switch:SW_Push | MX_Switch:SW_Cherry_MX_1.75u_PCB
 |  | SW55 | SW_Push | Switch:SW_Push | MX_Switch:SW_Cherry_MX_1.00u_PCB
 |  | SW56 | SW_Push | Switch:SW_Push | MX_Switch:SW_Cherry_MX_1.00u_PCB
 |  | SW57 | SW_Push | Switch:SW_Push | MX_Switch:SW_Cherry_MX_2.25u_PCB_ReversedStabilizers
 |  | SW58 | SW_Push | Switch:SW_Push | MX_Switch:SW_Cherry_MX_1.00u_PCB
 |  | SW59 | SW_Push | Switch:SW_Push | MX_Switch:SW_Cherry_MX_1.00u_PCB
 |  | SW60 | SW_Push | Switch:SW_Push | MX_Switch:SW_Cherry_MX_1.50u_PCB
 |  | SW61 | SW_Push | Switch:SW_Push | MX_Switch:SW_Cherry_MX_1.00u_PCB
 |  | SW62 | SW_Push | Switch:SW_Push | MX_Switch:SW_Cherry_MX_1.00u_PCB
 |  | SW63 | SW_Push | Switch:SW_Push | MX_Switch:SW_Cherry_MX_1.00u_PCB
 |  | SW64 | SW_Push | Switch:SW_Push | MX_Switch:SW_Cherry_MX_1.00u_PCB
 |  | SW65 | SW_Push | Switch:SW_Push | MX_Switch:SW_Cherry_MX_1.00u_PCB
 |  | SW66 | SW_Push | Switch:SW_Push | MX_Switch:SW_Cherry_MX_1.00u_PCB
 |  | SW67 | SW_Push | Switch:SW_Push | MX_Switch:SW_Cherry_MX_1.00u_PCB
 |  | SWR1 | SW_Push | Switch:SW_Push | Buttons_Switches_SMD:SW_SPST_TL3342
 |  | U1 | USBLC6-2SC6 | Power_Protection:USBLC6-2SC6 | TO_SOT_Packages_SMD:SOT-23-6_Handsoldering | http://www2.st.com/resource/en/datasheet/CD00050750.pdf
 |  | U2 | ATmega32U4-AU | MCU_Microchip_ATmega:ATmega32U4-AU | Housings_QFP:TQFP-44_10x10mm_Pitch0.8mm | http://ww1.microchip.com/downloads/en/DeviceDoc/Atmel-7766-8-bit-AVR-ATmega16U4-32U4_Datasheet.pdf
 |  | Y1 | Crystal_GND24 | Device:Crystal_GND24 | Crystal:Crystal_SMD_3225-4Pin_3.2x2.5mm | ~
Collated Components:
Item | Qty | Reference(s) | Value | LibPart | Footprint | Datasheet
1 | 2 | C1, C2 | 22pF | Device:C | Capacitor_SMD:C_0805_2012Metric | ~
2 | 1 | C3 | 10uF | Device:C | Capacitor_SMD:C_0805_2012Metric | ~
3 | 1 | C4 | 1uF (±10%) | Device:C | Capacitor_SMD:C_0805_2012Metric | ~
4 | 1 | C5 | 1uF | Device:C | Capacitor_SMD:C_0805_2012Metric | ~
5 | 4 | C6, C7, C8, C9 | 0.1uF | Device:C | Capacitor_SMD:C_0805_2012Metric | ~
6 | 67 | D1, D2, D3, D4, D5, D6, D7, D8, D9, D10, D11, D12, D13, D14, D15, D16, D17, D18, D19, D20, D21, D22, D23, D24, D25, D26, D27, D28, D29, D30, D31, D32, D33, D34, D35, D36, D37, D38, D39, D40, D41, D42, D43, D44, D45, D46, D47, D48, D49, D50, D51, D52, D53, D54, D55, D56, D57, D58, D59, D60, D61, D62, D63, D64, D65, D66, D67 | D | Device:D | Diodes_SMD:D_SOD-123 | ~
7 | 16 | D68, D69, D70, D71, D72, D73, D74, D75, D76, D77, D78, D79, D80, D81, D82, D83 | WS2812B | LED:WS2812B | LED_SMD:LED_WS2812B_PLCC4_5.0x5.0mm_P3.2mm | https://cdn-shop.adafruit.com/datasheets/WS2812B.pdf
8 | 8 | H1, H2, H3, H4, H5, H6, H7, H8 | MountingHole | Mechanical:MountingHole | Mounting_Holes:MountingHole_2.2mm_M2_Pad | ~
9 | 1 | J1 | USB_B_Micro | Connector:USB_B_Micro | Connectors_USB:USB_Micro-B_Molex-105017-0001 | ~
10 | 1 | J2 | MISO | Connector_Generic:Conn_01x01 | Pin_Headers:Pin_Header_Straight_1x01_Pitch2.54mm | ~
11 | 2 | J3, J12 | VCC | Connector_Generic:Conn_01x01 | Pin_Headers:Pin_Header_Straight_1x01_Pitch2.54mm | ~
12 | 1 | J4 | SCK | Connector_Generic:Conn_01x01 | Pin_Headers:Pin_Header_Straight_1x01_Pitch2.54mm | ~
13 | 1 | J5 | MOSI | Connector_Generic:Conn_01x01 | Pin_Headers:Pin_Header_Straight_1x01_Pitch2.54mm | ~
14 | 1 | J6 | RES | Connector_Generic:Conn_01x01 | Pin_Headers:Pin_Header_Straight_1x01_Pitch2.54mm | ~
15 | 2 | J7, J15 | GND | Connector_Generic:Conn_01x01 | Pin_Headers:Pin_Header_Straight_1x01_Pitch2.54mm | ~
16 | 1 | J8 | PF4 | Connector_Generic:Conn_01x01 | Pin_Headers:Pin_Header_Straight_1x01_Pitch2.54mm | ~
17 | 1 | J9 | PF5 | Connector_Generic:Conn_01x01 | Pin_Headers:Pin_Header_Straight_1x01_Pitch2.54mm | ~
18 | 1 | J10 | PF6 | Connector_Generic:Conn_01x01 | Pin_Headers:Pin_Header_Straight_1x01_Pitch2.54mm | ~
19 | 1 | J11 | PF7 | Connector_Generic:Conn_01x01 | Pin_Headers:Pin_Header_Straight_1x01_Pitch2.54mm | ~
20 | 1 | J13 | D+ | Connector_Generic:Conn_01x01 | Pin_Headers:Pin_Header_Straight_1x01_Pitch2.54mm | ~
21 | 1 | J14 | D- | Connector_Generic:Conn_01x01 | Pin_Headers:Pin_Header_Straight_1x01_Pitch2.54mm | ~
22 | 2 | R1, R2 | 22 | Device:R | Resistor_SMD:R_0805_2012Metric | ~
23 | 2 | R3, R4 | 10K | Device:R | Resistor_SMD:R_0805_2012Metric | ~
24 | 1 | R5 | 500 | Device:R | Resistor_SMD:R_0805_2012Metric | ~
25 | 56 | SW1, SW6, SW7, SW8, SW9, SW10, SW11, SW12, SW13, SW15, SW16, SW17, SW18, SW19, SW20, SW21, SW22, SW24, SW25, SW26, SW27, SW28, SW29, SW30, SW31, SW32, SW33, SW34, SW35, SW36, SW38, SW39, SW40, SW41, SW42, SW43, SW44, SW45, SW47, SW48, SW49, SW50, SW51, SW52, SW53, SW55, SW56, SW58, SW59, SW61, SW62, SW63, SW64, SW65, SW66, SW67 | SW_Push | Switch:SW_Push | MX_Switch:SW_Cherry_MX_1.00u_PCB
26 | 5 | SW2, SW5, SW14, SW46, SW60 | SW_Push | Switch:SW_Push | MX_Switch:SW_Cherry_MX_1.50u_PCB
27 | 2 | SW3, SW54 | SW_Push | Switch:SW_Push | MX_Switch:SW_Cherry_MX_1.75u_PCB
28 | 1 | SW4 | SW_Push | Switch:SW_Push | MX_Switch:SW_Cherry_MX_2.25u_PCB
29 | 1 | SW23 | SW_Push | Switch:SW_Push | MX_Switch:SW_Cherry_MX_2.00u_PCB_ReversedStabilizers
30 | 1 | SW37 | SW_Push | Switch:SW_Push | MX_Switch:SW_Cherry_MX_2.75u_PCB_ReversedStabilizers
31 | 1 | SW57 | SW_Push | Switch:SW_Push | MX_Switch:SW_Cherry_MX_2.25u_PCB_ReversedStabilizers
32 | 1 | SWR1 | SW_Push | Switch:SW_Push | Buttons_Switches_SMD:SW_SPST_TL3342
33 | 1 | U1 | USBLC6-2SC6 | Power_Protection:USBLC6-2SC6 | TO_SOT_Packages_SMD:SOT-23-6_Handsoldering | http://www2.st.com/resource/en/datasheet/CD00050750.pdf
34 | 1 | U2 | ATmega32U4-AU | MCU_Microchip_ATmega:ATmega32U4-AU | Housings_QFP:TQFP-44_10x10mm_Pitch0.8mm | http://ww1.microchip.com/downloads/en/DeviceDoc/Atmel-7766-8-bit-AVR-ATmega16U4-32U4_Datasheet.pdf
35 | 1 | Y1 | Crystal_GND24 | Device:Crystal_GND24 | Crystal:Crystal_SMD_3225-4Pin_3.2x2.5mm | ~

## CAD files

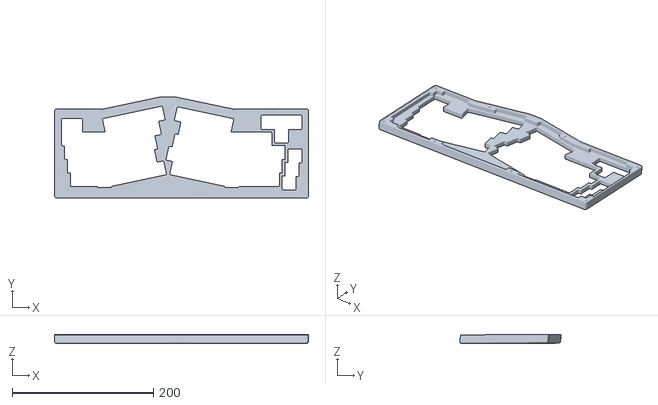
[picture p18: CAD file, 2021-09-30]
case_stls/new_top-Top_Case_without_logo.stl
359.3 x 143.4 x 12.9

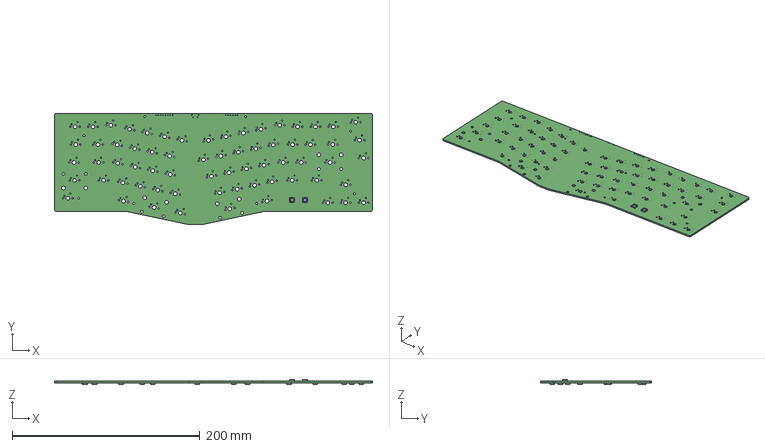
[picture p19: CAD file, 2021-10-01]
PCB files/blossom_pcb/arisu.step
339.1 x 118.7 x 4.90 mm

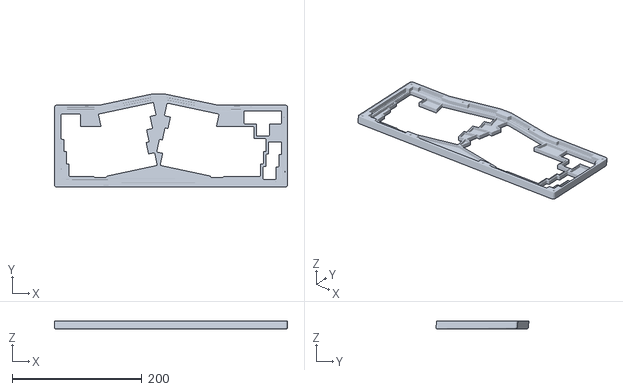
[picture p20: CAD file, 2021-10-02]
production/case/U_Case.stl
359.3 x 143.4 x 12.9

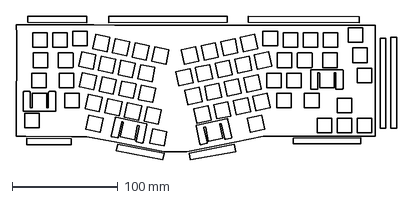
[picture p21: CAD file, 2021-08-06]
production/gasket/gasket_n_sdl.dxf
360.5 x 136.1 mm

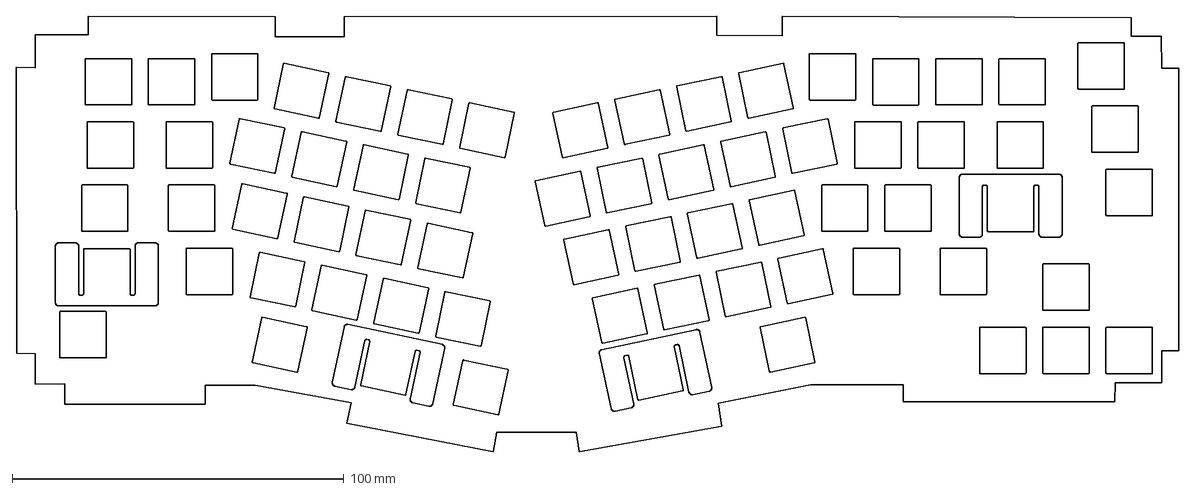
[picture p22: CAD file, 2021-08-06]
production/plate/plate.dxf
350.4 x 131.4 mm

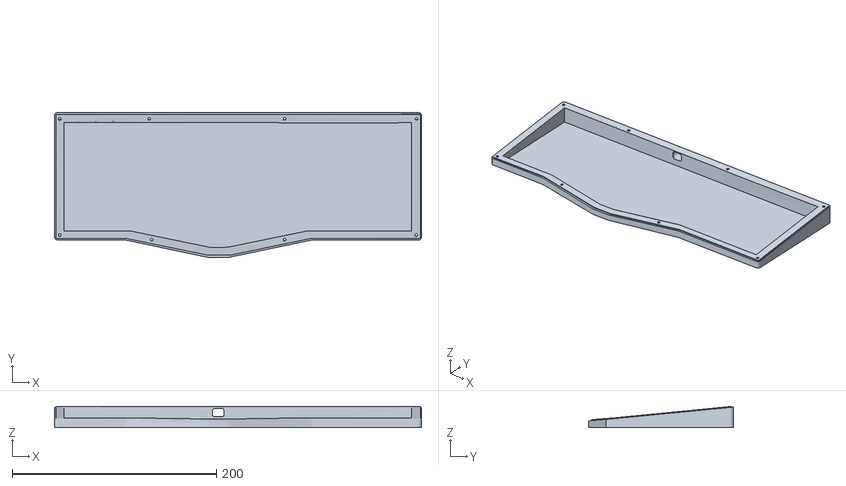
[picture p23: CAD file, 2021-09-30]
case_stls/new_top-Bottom_Case_without_gasket_hole.stl
359.2 x 141.8 x 20.7

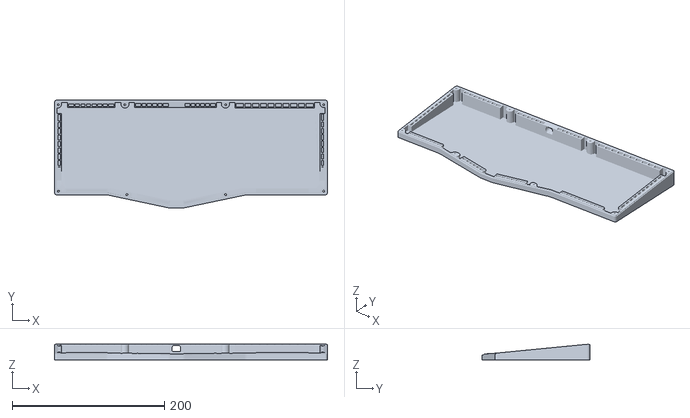
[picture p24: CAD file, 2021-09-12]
production/case/B_Case.stl
359.2 x 141.8 x 20.7

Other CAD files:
case_stls/new_top-Top_Case.stl
case_stls/lower.stl

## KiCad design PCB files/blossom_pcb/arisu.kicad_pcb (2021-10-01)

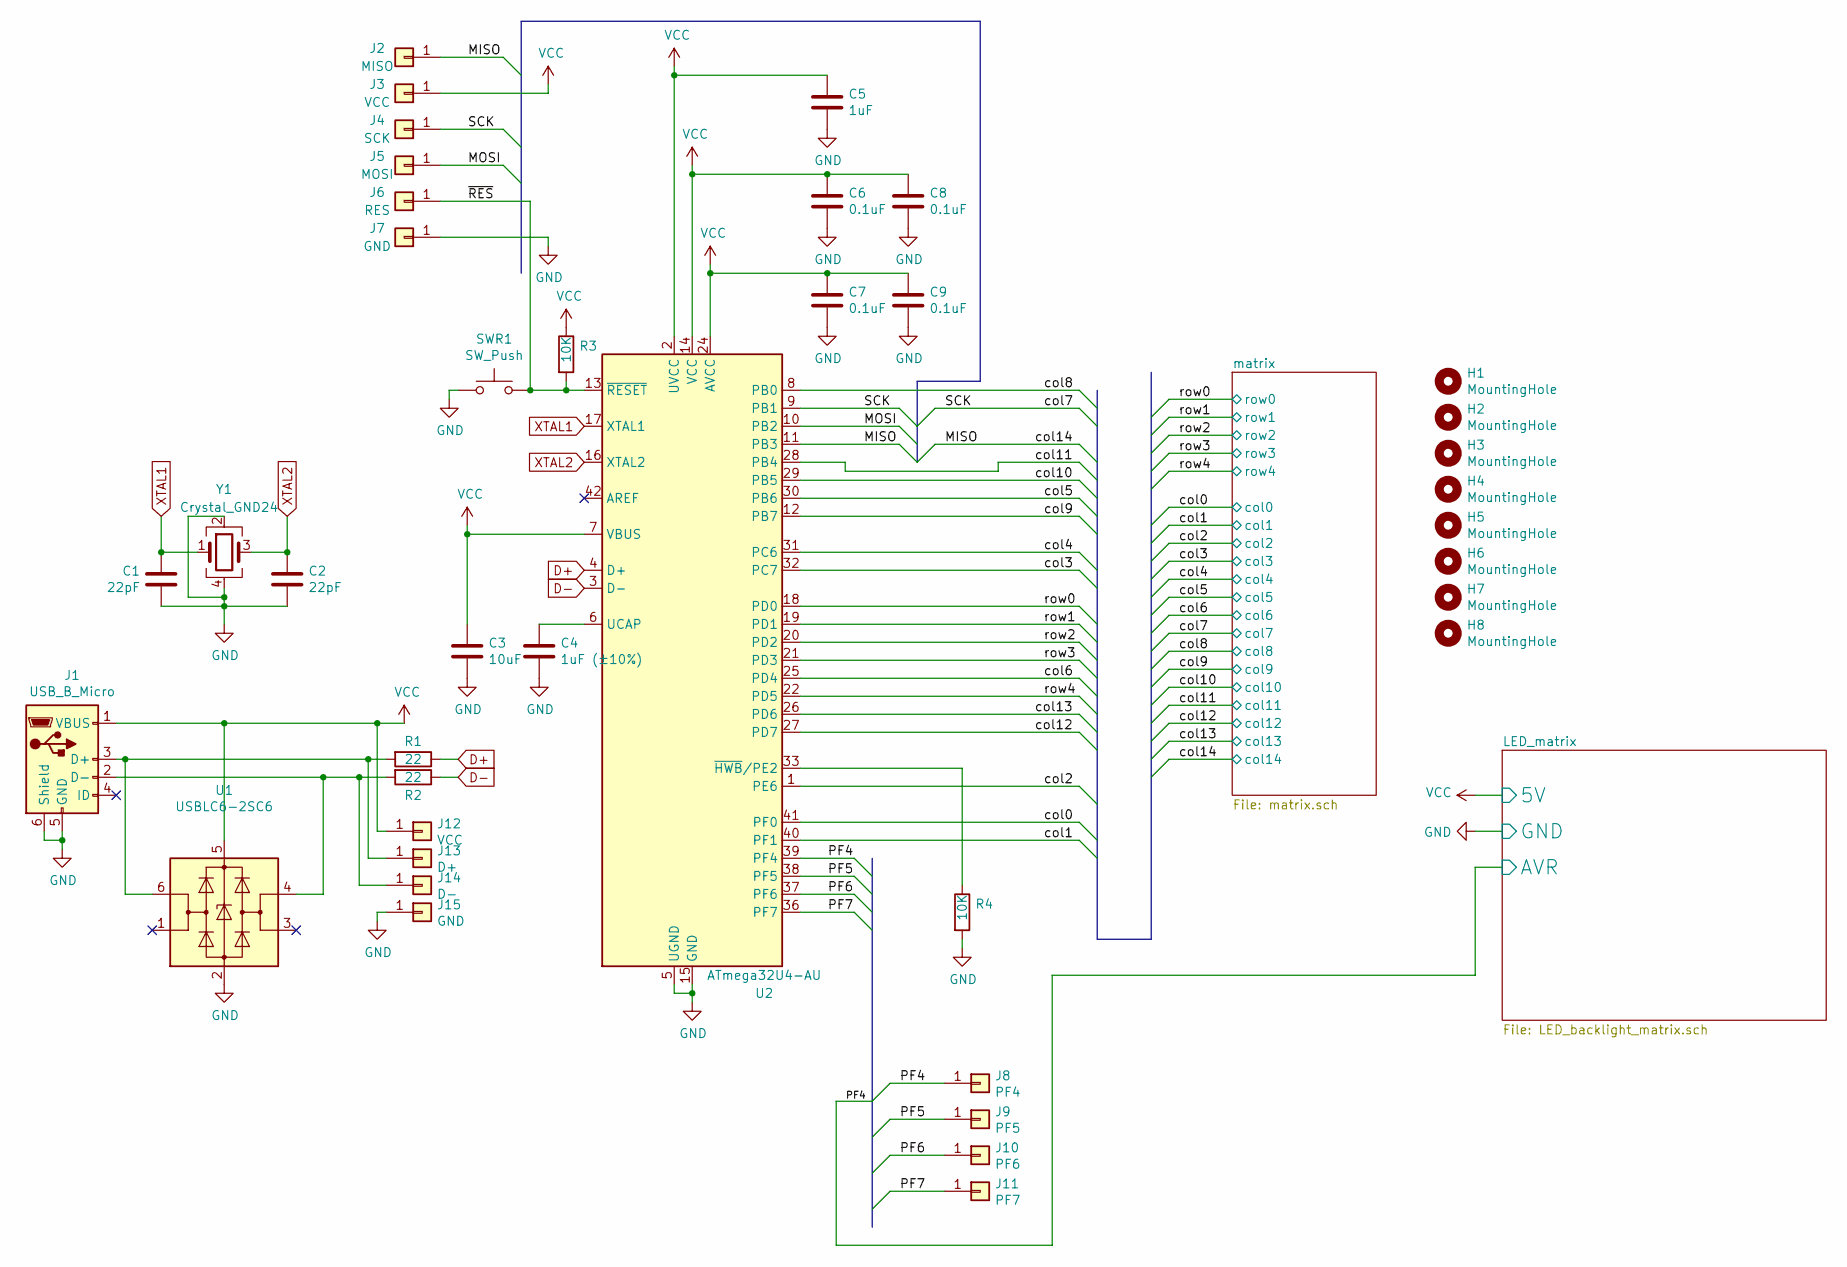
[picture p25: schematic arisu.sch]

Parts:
C1, C2: 22pF; C_0805_2012Metric
C3: 10uF; C_0805_2012Metric
C4: 1uF (±10%); C_0805_2012Metric
C5: 1uF; C_0805_2012Metric
C6, C7, C8, C9: 0.1uF; C_0805_2012Metric
H1, H2, H3, H4, H5, H6, H7, H8: MountingHole; MountingHole_2.2mm_M2_Pad
J1: USB_B_Micro; USB_Micro-B_Molex-105017-0001
J2: MISO; Pin_Header_Straight_1x01_Pitch2.54mm
J3, J12: VCC; Pin_Header_Straight_1x01_Pitch2.54mm
J4: SCK; Pin_Header_Straight_1x01_Pitch2.54mm
J5: MOSI; Pin_Header_Straight_1x01_Pitch2.54mm
J6: RES; Pin_Header_Straight_1x01_Pitch2.54mm
J7, J15: GND; Pin_Header_Straight_1x01_Pitch2.54mm
J8: PF4; Pin_Header_Straight_1x01_Pitch2.54mm
J9: PF5; Pin_Header_Straight_1x01_Pitch2.54mm
J10: PF6; Pin_Header_Straight_1x01_Pitch2.54mm
J11: PF7; Pin_Header_Straight_1x01_Pitch2.54mm
J13: D+; Pin_Header_Straight_1x01_Pitch2.54mm
J14: D-; Pin_Header_Straight_1x01_Pitch2.54mm
R1, R2: 22; R_0805_2012Metric
R3, R4: 10K; R_0805_2012Metric
SWR1: SW_Push; SW_SPST_TL3342
U1: USBLC6-2SC6; SOT-23-6_Handsoldering
U2: ATmega32U4-AU; TQFP-44_10x10mm_Pitch0.8mm
Y1: Crystal_GND24; Crystal_SMD_3225-4Pin_3.2x2.5mm

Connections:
/MISO: J2.1, U2.11 (PB3); also elsewhere on the board
/MOSI: J5.1, U2.10 (PB2)
/PF4: J8.1, U2.39 (PF4); also elsewhere on the board
/PF5: J9.1, U2.38 (PF5)
/PF6: J10.1, U2.37 (PF6)
/PF7: J11.1, U2.36 (PF7)
/SCK: J4.1, U2.9 (PB1); also elsewhere on the board
/col0: U2.41 (PF0); also elsewhere on the board
/col1: U2.40 (PF1); also elsewhere on the board
/col2: U2.1 (PE6); also elsewhere on the board
/col3: U2.32 (PC7); also elsewhere on the board
/col4: U2.31 (PC6); also elsewhere on the board
/col5: U2.30 (PB6); also elsewhere on the board
/col6: U2.25 (PD4); also elsewhere on the board
/col8: U2.8 (PB0); also elsewhere on the board
/col9: U2.12 (PB7); also elsewhere on the board
/col10: U2.29 (PB5); also elsewhere on the board
/col11: U2.28 (PB4); also elsewhere on the board
/col12: U2.27 (PD7); also elsewhere on the board
/col13: U2.26 (PD6); also elsewhere on the board
/row0: U2.18 (PD0); also elsewhere on the board
/row1: U2.19 (PD1); also elsewhere on the board
/row2: U2.20 (PD2); also elsewhere on the board
/row3: U2.21 (PD3); also elsewhere on the board
/row4: U2.22 (PD5); also elsewhere on the board
/~RES~: J6.1, R3.2, SWR1.2, U2.13 (~RESET)
D+: R1.1, U2.4 (D+)
D-: R2.1, U2.3 (D-)
GND: C1.1, C2.2, C3.2, C4.2, C5.2, C6.2, C7.2, C8.2, C9.2, J1.5 (GND), J1.6 (Shield), J7.1, J15.1, R4.2, SWR1.1, U1.2 (GND), U2.5 (UGND), U2.15 (GND), U2.23 (GND), U2.35 (GND), U2.43 (GND), Y1.2, Y1.4; also elsewhere on the board
unnamed: C4.1, U2.6 (UCAP)
unnamed: J1.2 (D-), J14.1, R2.2, U1.4 (I/O2)
unnamed: J1.3 (D+), J13.1, R1.2, U1.6 (I/O1)
unnamed: R4.1, U2.33 (~HWB~/PE2)
VCC: C3.1, C5.1, C6.1, C7.1, C8.1, C9.1, J1.1 (VBUS), J3.1, J12.1, R3.1, U1.5 (VBUS), U2.2 (UVCC), U2.7 (VBUS), U2.14 (VCC), U2.24 (AVCC), U2.34 (VCC), U2.44 (AVCC); also elsewhere on the board
XTAL1: C1.2, U2.17 (XTAL1), Y1.1
XTAL2: C2.1, U2.16 (XTAL2), Y1.3

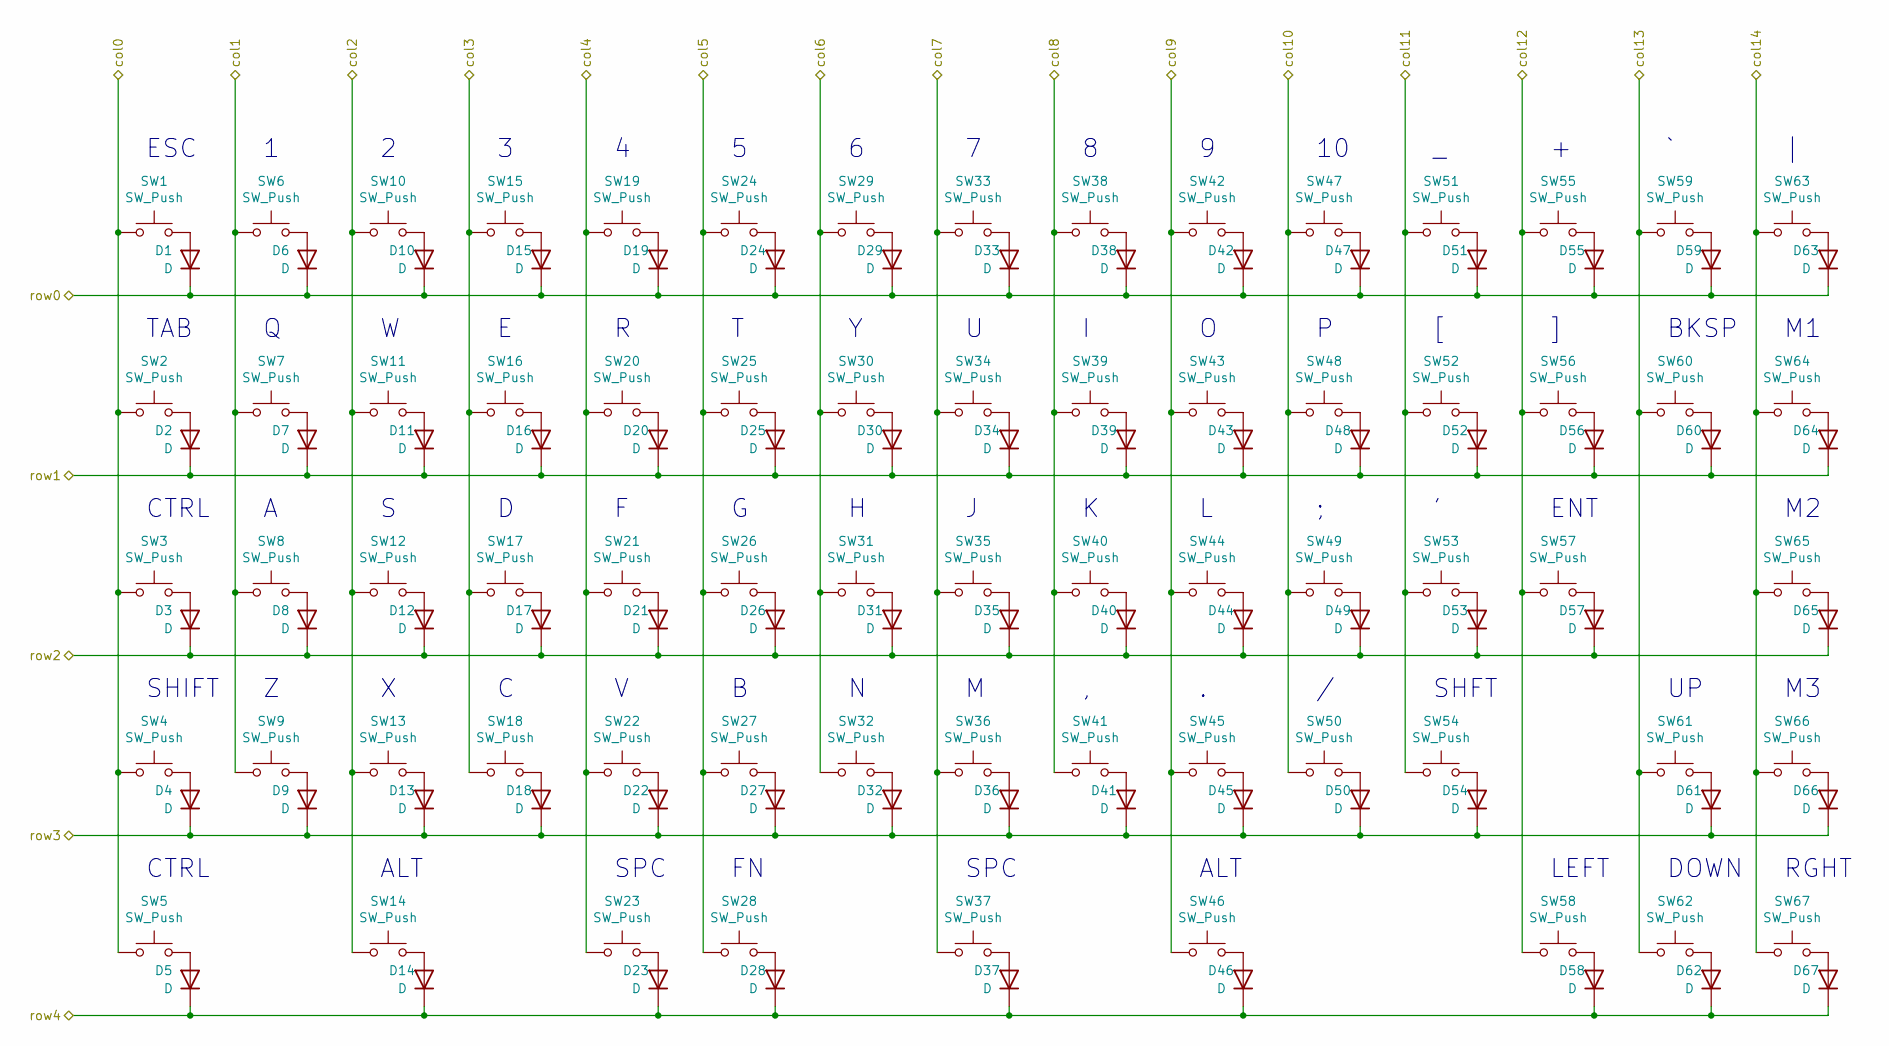
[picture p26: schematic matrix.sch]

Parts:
D1, D2, D3, D4, D5, D6, D7, D8, D9, D10, D11, D12, D13, D14, D15, D16, D17, D18, D19, D20, D21, D22, D23, D24, D25, D26, D27, D28, D29, D30, D31, D32, D33, D34, D35, D36, D37, D38, D39, D40, D41, D42, D43, D44, D45, D46, D47, D48, D49, D50, D51, D52, D53, D54, D55, D56, D57, D58, D59, D60, D61, D62, D63, D64, D65, D66, D67: D; D_SOD-123
SW1, SW6, SW7, SW8, SW9, SW10, SW11, SW12, SW13, SW15, SW16, SW17, SW18, SW19, SW20, SW21, SW22, SW24, SW25, SW26, SW27, SW28, SW29, SW30, SW31, SW32, SW33, SW34, SW35, SW36, SW38, SW39, SW40, SW41, SW42, SW43, SW44, SW45, SW47, SW48, SW49, SW50, SW51, SW52, SW53, SW55, SW56, SW58, SW59, SW61, SW62, SW63, SW64, SW65, SW66, SW67: SW_Push; SW_Cherry_MX_1.00u_PCB
SW2, SW5, SW14, SW46, SW60: SW_Push; SW_Cherry_MX_1.50u_PCB
SW3, SW54: SW_Push; SW_Cherry_MX_1.75u_PCB
SW4: SW_Push; SW_Cherry_MX_2.25u_PCB
SW23: SW_Push; SW_Cherry_MX_2.00u_PCB_ReversedStabilizers
SW37: SW_Push; SW_Cherry_MX_2.75u_PCB_ReversedStabilizers
SW57: SW_Push; SW_Cherry_MX_2.25u_PCB_ReversedStabilizers

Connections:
/MISO: SW63.1, SW64.1, SW65.1, SW66.1, SW67.1; also elsewhere on the board
/SCK: SW33.1, SW34.1, SW35.1, SW36.1, SW37.1; also elsewhere on the board
/col0: SW1.1, SW2.1, SW3.1, SW4.1, SW5.1; also elsewhere on the board
/col1: SW6.1, SW7.1, SW8.1, SW9.1; also elsewhere on the board
/col2: SW10.1, SW11.1, SW12.1, SW13.1, SW14.1; also elsewhere on the board
/col3: SW15.1, SW16.1, SW17.1, SW18.1; also elsewhere on the board
/col4: SW19.1, SW20.1, SW21.1, SW22.1, SW23.1; also elsewhere on the board
/col5: SW24.1, SW25.1, SW26.1, SW27.1, SW28.1; also elsewhere on the board
/col6: SW29.1, SW30.1, SW31.1, SW32.1; also elsewhere on the board
/col8: SW38.1, SW39.1, SW40.1, SW41.1; also elsewhere on the board
/col9: SW42.1, SW43.1, SW44.1, SW45.1, SW46.1; also elsewhere on the board
/col10: SW47.1, SW48.1, SW49.1, SW50.1; also elsewhere on the board
/col11: SW51.1, SW52.1, SW53.1, SW54.1; also elsewhere on the board
/col12: SW55.1, SW56.1, SW57.1, SW58.1; also elsewhere on the board
/col13: SW59.1, SW60.1, SW61.1, SW62.1; also elsewhere on the board
/row0: D1.1 (K), D6.1 (K), D10.1 (K), D15.1 (K), D19.1 (K), D24.1 (K), D29.1 (K), D33.1 (K), D38.1 (K), D42.1 (K), D47.1 (K), D51.1 (K), D55.1 (K), D59.1 (K), D63.1 (K); also elsewhere on the board
/row1: D2.1 (K), D7.1 (K), D11.1 (K), D16.1 (K), D20.1 (K), D25.1 (K), D30.1 (K), D34.1 (K), D39.1 (K), D43.1 (K), D48.1 (K), D52.1 (K), D56.1 (K), D60.1 (K), D64.1 (K); also elsewhere on the board
/row2: D3.1 (K), D8.1 (K), D12.1 (K), D17.1 (K), D21.1 (K), D26.1 (K), D31.1 (K), D35.1 (K), D40.1 (K), D44.1 (K), D49.1 (K), D53.1 (K), D57.1 (K), D65.1 (K); also elsewhere on the board
/row3: D4.1 (K), D9.1 (K), D13.1 (K), D18.1 (K), D22.1 (K), D27.1 (K), D32.1 (K), D36.1 (K), D41.1 (K), D45.1 (K), D50.1 (K), D54.1 (K), D61.1 (K), D66.1 (K); also elsewhere on the board
/row4: D5.1 (K), D14.1 (K), D23.1 (K), D28.1 (K), D37.1 (K), D46.1 (K), D58.1 (K), D62.1 (K), D67.1 (K); also elsewhere on the board
unnamed: D1.2 (A), SW1.2
unnamed: D2.2 (A), SW2.2
unnamed: D3.2 (A), SW3.2
unnamed: D4.2 (A), SW4.2
unnamed: D5.2 (A), SW5.2
unnamed: D6.2 (A), SW6.2
unnamed: D7.2 (A), SW7.2
unnamed: D8.2 (A), SW8.2
unnamed: D9.2 (A), SW9.2
unnamed: D10.2 (A), SW10.2
unnamed: D11.2 (A), SW11.2
unnamed: D12.2 (A), SW12.2
unnamed: D13.2 (A), SW13.2
unnamed: D14.2 (A), SW14.2
unnamed: D15.2 (A), SW15.2
unnamed: D16.2 (A), SW16.2
unnamed: D17.2 (A), SW17.2
unnamed: D18.2 (A), SW18.2
unnamed: D19.2 (A), SW19.2
unnamed: D20.2 (A), SW20.2
unnamed: D21.2 (A), SW21.2
unnamed: D22.2 (A), SW22.2
unnamed: D23.2 (A), SW23.2
unnamed: D24.2 (A), SW24.2
unnamed: D25.2 (A), SW25.2
unnamed: D26.2 (A), SW26.2
unnamed: D27.2 (A), SW27.2
unnamed: D28.2 (A), SW28.2
unnamed: D29.2 (A), SW29.2
unnamed: D30.2 (A), SW30.2
unnamed: D31.2 (A), SW31.2
unnamed: D32.2 (A), SW32.2
unnamed: D33.2 (A), SW33.2
unnamed: D34.2 (A), SW34.2
unnamed: D35.2 (A), SW35.2
unnamed: D36.2 (A), SW36.2
unnamed: D37.2 (A), SW37.2
unnamed: D38.2 (A), SW38.2
unnamed: D39.2 (A), SW39.2
unnamed: D40.2 (A), SW40.2
unnamed: D41.2 (A), SW41.2
unnamed: D42.2 (A), SW42.2
unnamed: D43.2 (A), SW43.2
unnamed: D44.2 (A), SW44.2
unnamed: D45.2 (A), SW45.2
unnamed: D46.2 (A), SW46.2
unnamed: D47.2 (A), SW47.2
unnamed: D48.2 (A), SW48.2
unnamed: D49.2 (A), SW49.2
unnamed: D50.2 (A), SW50.2
unnamed: D51.2 (A), SW51.2
unnamed: D52.2 (A), SW52.2
unnamed: D53.2 (A), SW53.2
unnamed: D54.2 (A), SW54.2
unnamed: D55.2 (A), SW55.2
unnamed: D56.2 (A), SW56.2
unnamed: D57.2 (A), SW57.2
unnamed: D58.2 (A), SW58.2
unnamed: D59.2 (A), SW59.2
unnamed: D60.2 (A), SW60.2
unnamed: D61.2 (A), SW61.2
unnamed: D62.2 (A), SW62.2
unnamed: D63.2 (A), SW63.2
unnamed: D64.2 (A), SW64.2
unnamed: D65.2 (A), SW65.2
unnamed: D66.2 (A), SW66.2
unnamed: D67.2 (A), SW67.2

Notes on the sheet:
ESC
TAB
BKSP
CTRL
ENT
SHIFT
SHFT
ALT
SPC
DOWN
LEFT
RGHT

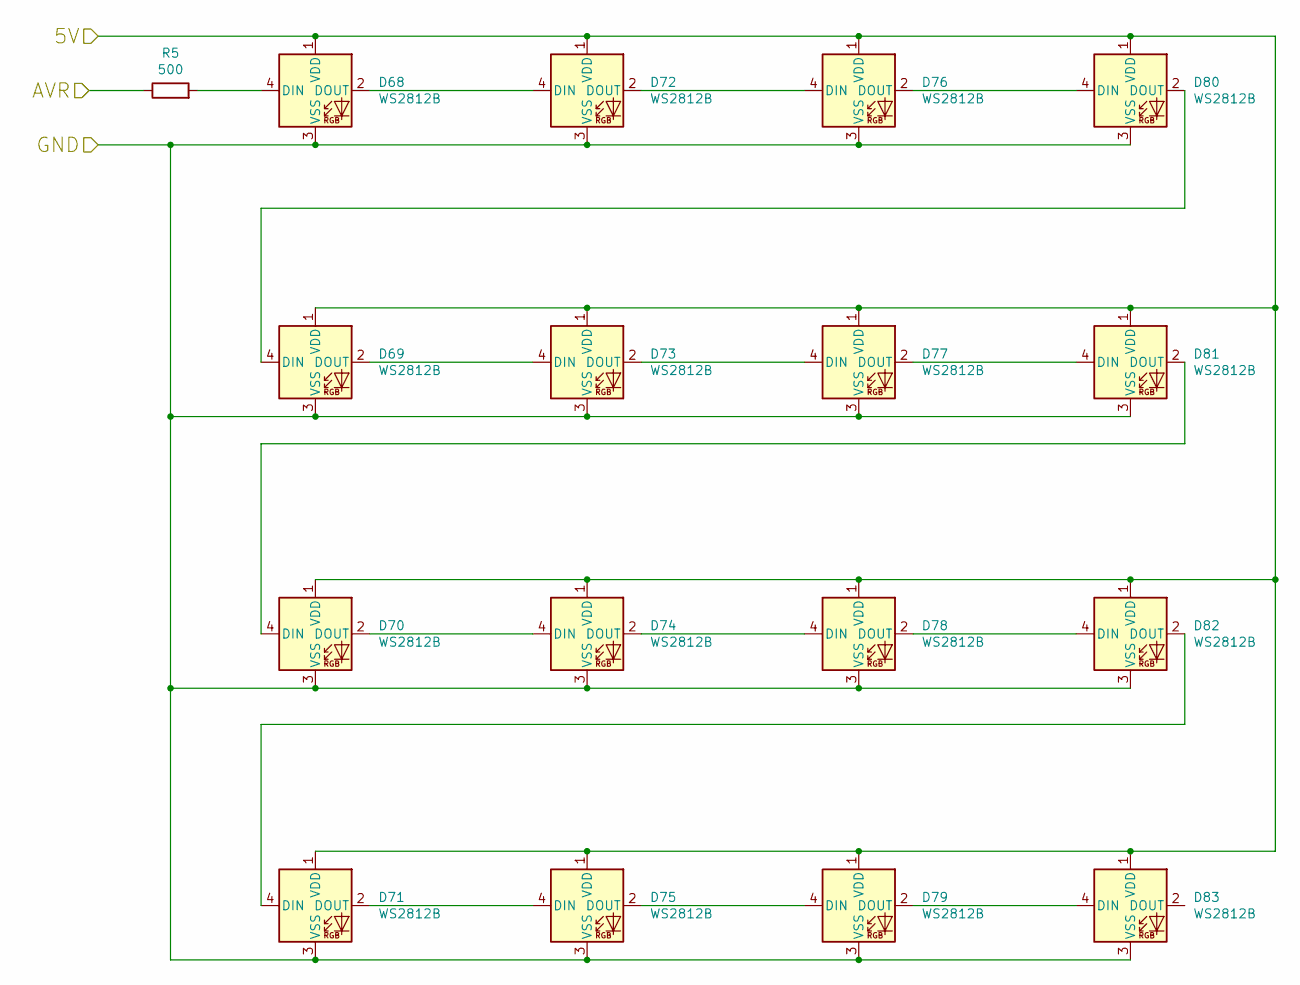
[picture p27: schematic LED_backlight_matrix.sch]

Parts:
D68, D69, D70, D71, D72, D73, D74, D75, D76, D77, D78, D79, D80, D81, D82, D83: WS2812B; LED_WS2812B_PLCC4_5.0x5.0mm_P3.2mm
R5: 500; R_0805_2012Metric

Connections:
/PF4: R5.1; also elsewhere on the board
GND: D68.3 (VSS), D69.3 (VSS), D70.3 (VSS), D71.3 (VSS), D72.3 (VSS), D73.3 (VSS), D74.3 (VSS), D75.3 (VSS), D76.3 (VSS), D77.3 (VSS), D78.3 (VSS), D79.3 (VSS), D80.3 (VSS), D81.3 (VSS), D82.3 (VSS), D83.3 (VSS); also elsewhere on the board
unnamed: D68.2 (DOUT), D72.4 (DIN)
unnamed: D68.4 (DIN), R5.2
unnamed: D69.2 (DOUT), D73.4 (DIN)
unnamed: D69.4 (DIN), D80.2 (DOUT)
unnamed: D70.2 (DOUT), D74.4 (DIN)
unnamed: D70.4 (DIN), D81.2 (DOUT)
unnamed: D71.2 (DOUT), D75.4 (DIN)
unnamed: D71.4 (DIN), D82.2 (DOUT)
unnamed: D72.2 (DOUT), D76.4 (DIN)
unnamed: D73.2 (DOUT), D77.4 (DIN)
unnamed: D74.2 (DOUT), D78.4 (DIN)
unnamed: D75.2 (DOUT), D79.4 (DIN)
unnamed: D76.2 (DOUT), D80.4 (DIN)
unnamed: D77.2 (DOUT), D81.4 (DIN)
unnamed: D78.2 (DOUT), D82.4 (DIN)
unnamed: D79.2 (DOUT), D83.4 (DIN)
VCC: D68.1 (VDD), D69.1 (VDD), D70.1 (VDD), D71.1 (VDD), D72.1 (VDD), D73.1 (VDD), D74.1 (VDD), D75.1 (VDD), D76.1 (VDD), D77.1 (VDD), D78.1 (VDD), D79.1 (VDD), D80.1 (VDD), D81.1 (VDD), D82.1 (VDD), D83.1 (VDD); also elsewhere on the board

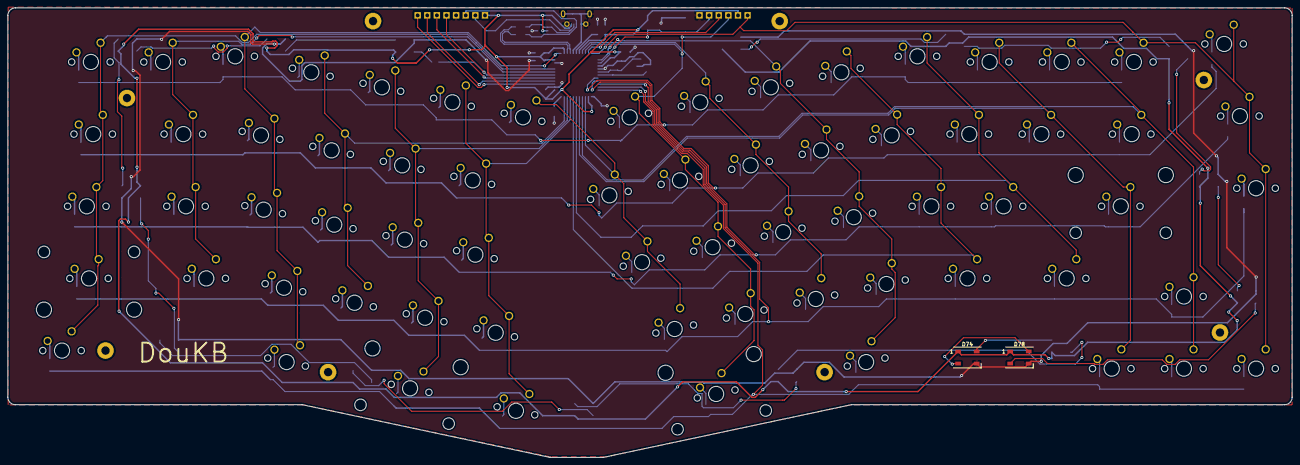
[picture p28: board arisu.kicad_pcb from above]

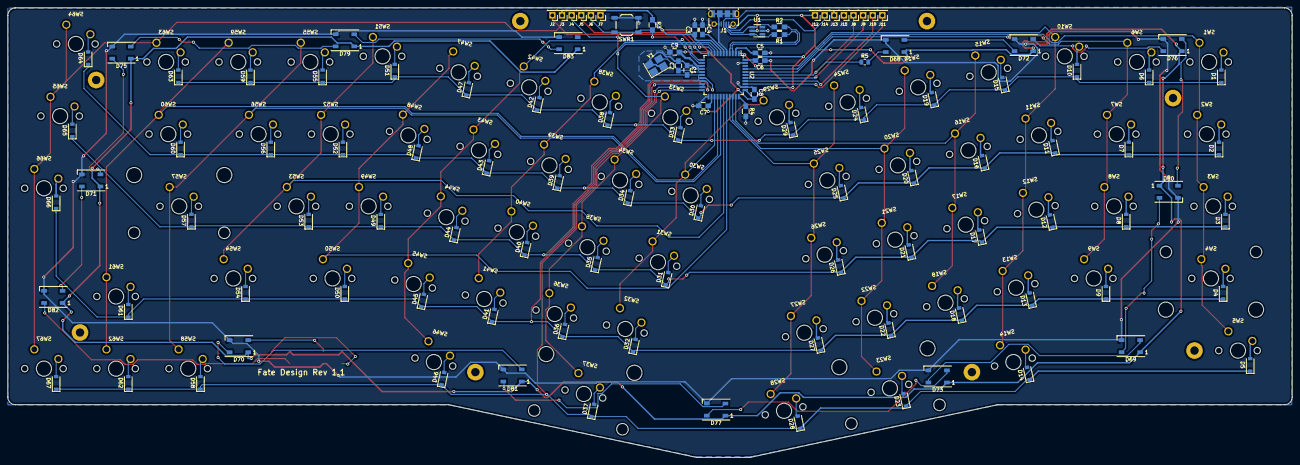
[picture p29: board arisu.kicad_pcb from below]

Board: 2 copper layers, 339.1 x 118.7 mm, 191 parts (114 on the bottom side), 119 nets.

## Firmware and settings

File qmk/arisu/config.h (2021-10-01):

/*
Copyright 2019 Fate

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
You should have received a copy of the GNU General Public License
along with this program.  If not, see <http://www.gnu.org/licenses/>.
*/

#pragma once

#include "config_common.h"

/* USB Device descriptor parameter */
#define VENDOR_ID       0xFA7E
#define PRODUCT_ID      0x0000
#define DEVICE_VER      0x0001
#define MANUFACTURER    Fate
#define PRODUCT         arisu

/* key matrix size */
#define MATRIX_ROWS 5
#define MATRIX_COLS 15

/*
 * Keyboard Matrix Assignments
 *
 * Change this to how you wired your keyboard
 * COLS: AVR pins used for columns, left to right
 * ROWS: AVR pins used for rows, top to bottom
 * DIODE_DIRECTION: COL2ROW = COL = Anode (+), ROW = Cathode (-, marked on diode)
 *                  ROW2COL = ROW = Anode (+), COL = Cathode (-, marked on diode)
 *
*/
#define MATRIX_ROW_PINS { D0, D1, D2, D3, D5 }
#define MATRIX_COL_PINS { F0, F1, E6, C7, C6, B6, D4, B1, B0, B7, B5, B4, D7, D6, B3 }
#define UNUSED_PINS

/* COL2ROW, ROW2COL*/
#define DIODE_DIRECTION COL2ROW

// #define BACKLIGHT_PIN B7
// #define BACKLIGHT_BREATHING
// #define BACKLIGHT_LEVELS 3

#define RGB_DI_PIN F4
#ifdef RGB_DI_PIN
  #define RGBLED_NUM 16
  #define RGBLIGHT_HUE_STEP 8
  #define RGBLIGHT_SAT_STEP 8
  #define RGBLIGHT_VAL_STEP 8
  #define RGBLIGHT_LIMIT_VAL 255 /* The maximum brightness level */
  #define RGBLIGHT_SLEEP  /* If defined, the RGB lighting will be switched off when the host goes to sleep */
/*== all animations enable ==*/
  #define RGBLIGHT_ANIMATIONS
/*== or choose animations ==*/
//   #define RGBLIGHT_EFFECT_BREATHING
//   #define RGBLIGHT_EFFECT_RAINBOW_MOOD
//   #define RGBLIGHT_EFFECT_RAINBOW_SWIRL
//   #define RGBLIGHT_EFFECT_SNAKE
//   #define RGBLIGHT_EFFECT_KNIGHT
//   #define RGBLIGHT_EFFECT_CHRISTMAS
//   #define RGBLIGHT_EFFECT_STATIC_GRADIENT
//   #define RGBLIGHT_EFFECT_RGB_TEST
//   #define RGBLIGHT_EFFECT_ALTERNATING
#endif

/* Debounce reduces chatter (unintended double-presses) - set 0 if debouncing is not needed */
#define DEBOUNCE 5

/* define if matrix has ghost (lacks anti-ghosting diodes) */
//#define MATRIX_HAS_GHOST

/* number of backlight levels */

/* Mechanical locking support. Use KC_LCAP, KC_LNUM or KC_LSCR instead in keymap */
#define LOCKING_SUPPORT_ENABLE
/* Locking resynchronize hack */
#define LOCKING_RESYNC_ENABLE

/* If defined, GRAVE_ESC will always act as ESC when CTRL is held.
 * This is userful for the Windows task manager shortcut (ctrl+shift+esc).
 */
// #define GRAVE_ESC_CTRL_OVERRIDE

/*
 * Force NKRO
 *
 * Force NKRO (nKey Rollover) to be enabled by default, regardless of the saved
 * state in the bootmagic EEPROM settings. (Note that NKRO must be enabled in the
 * makefile for this to work.)
 *
 * If forced on, NKRO can be disabled via magic key (default = LShift+RShift+N)
 * until the next keyboard reset.
 *
 * NKRO may prevent your keystrokes from being detected in the BIOS, but it is
 * fully operational during normal computer usage.
 *
 * For a less heavy-handed approach, enable NKRO via magic key (LShift+RShift+N)
 * or via bootmagic (hold SPACE+N while plugging in the keyboard). Once set by
 * bootmagic, NKRO mode will always be enabled until it is toggled again during a
 * power-up.
 *
 */
//#define FORCE_NKRO

/*
 * Feature disable options
 *  These options are also useful to firmware size reduction.
 */

/* disable debug print */
//#define NO_DEBUG

/* disable print */
//#define NO_PRINT

/* disable action features */
//#define NO_ACTION_LAYER
//#define NO_ACTION_TAPPING
//#define NO_ACTION_ONESHOT
//#define NO_ACTION_MACRO
//#define NO_ACTION_FUNCTION

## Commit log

2021-08-06 Added stl pcb dxf render
    [arisu.csv, arisu_bom_1.0.csv, gaskets.dxf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]
2021-08-07 Done desgin rule check on pcb and removed outlying wiring
    [gaskets.dxf]
2021-08-07 Some adjustments
    Increase height for upper casing
    [lower.stl, upper.stl]
2021-08-14 repaired non manifold things on upper case
    [new_top-Bottom_Case.stl, new_top-Top_Case.stl, upper.stl]
2021-09-08 minor fix
    [new_top-Top_Case.stl]
2021-09-08 fix top and add bevel
    [new_top-Bottom_Case.stl, new_top-Top_Case.stl]
2021-09-12 some updates
    [new_top-Bottom_Case.stl, new_top-Bottom_Case_without_gasket_hole.stl, new_top-Top_Case.stl]
2021-09-30 update no hole case thing
    [new_top-Bottom_Case_without_gasket_hole.stl]
2021-09-30 update to no gasket hole thing
    [new_top-Bottom_Case_without_gasket_hole.stl]
2021-09-30 added case without logo
    [new_top-Top_Case_without_logo.stl]
2021-10-01 Added keyboard/arisu/ config.h rbg pin
2021-10-01 added arisu pcb
    [LED_backlight_matrix.sch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]
2021-10-02 added cost reduction holes
    [new_top-Top_Case_with_hole_thing.stl]
2021-11-12 update production folder
    [arisu-B_Cu.gbr, arisu-B_Mask.gbr, arisu-B_Paste.gbr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]
2021-11-12 Changed names
    [B_Case.stl, U_Case.stl, gasket_n_sdl.dxf]

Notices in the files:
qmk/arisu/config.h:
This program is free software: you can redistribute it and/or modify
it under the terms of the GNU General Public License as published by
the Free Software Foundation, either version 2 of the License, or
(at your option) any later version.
